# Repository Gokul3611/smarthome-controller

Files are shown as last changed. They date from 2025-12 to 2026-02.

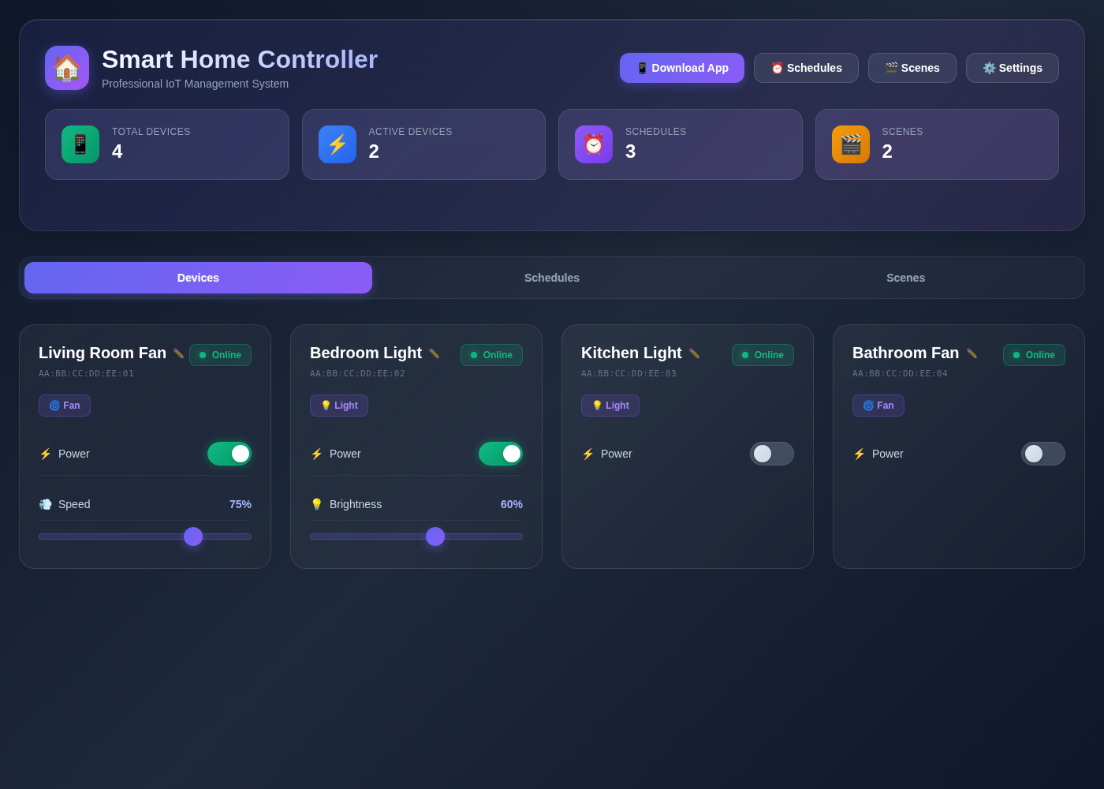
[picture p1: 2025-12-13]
docs/ui-redesign-preview.png

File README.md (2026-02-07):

"# Smart Home Controller





Full-stack IoT home automation system with ESP32 firmware, Google Apps Script backend, web dashboard, and Flutter mobile app. Controls 4 AC load channels via TRIAC phase-angle dimming with cloud synchronization, scheduling, and Amazon Alexa voice control.

## Project Status

**Maturity**: Portfolio project / advanced prototype
**Tested on**: ESP32-WROOM-32 with custom TRIAC controller board
**Known limitations**:
- Google Assistant integration (SinricPro) is stubbed but not yet functional
- No automated test suite for firmware or backend
- Flutter app requires manual API URL configuration

**What works**:
- 4-channel TRIAC phase-angle control with zero-cross detection
- Amazon Alexa voice control (via Espalexa, local network)
- Google Apps Script cloud backend with polling
- Web dashboard with real-time device control
- Flutter mobile app with device control, schedules, and scenes
- OTA firmware updates with rollback protection
- Scene and schedule automation
- WebSocket real-time state sync
- Persistent storage across reboots
- GitHub Actions CI for automated APK builds

**Not yet implemented**:
- Google Assistant control (SinricPro code is stubbed)
- Automated tests

## UI Preview

Smart Home Controller Dashboard

*Web dashboard with real-time device control and system statistics*

## Quick Start

1. **Deploy backend** — Copy `backend/google-apps-script/` files to a Google Apps Script project and deploy as a web app. See [Deployment Guide](./DEPLOYMENT.md).
2. **Flash firmware** — Open `firmware/main/main.ino` in Arduino IDE, set your Apps Script URL, and upload to ESP32. See [Installation Guide](./INSTALL.md).
3. **Build mobile app** — Run `flutter build apk --release` in `frontend/flutter project/demo/`. Or download from [Releases](https://github.com/Gokul3611/smarthome-controller/releases/latest).

## Documentation

- [Deployment Guide](./DEPLOYMENT.md) — Full system setup
- [Installation Guide](./INSTALL.md) — Firmware and hardware setup
- [Features List](./FEATURES.md) — Complete feature documentation
- [Hardware Guide](./hardware/README.md) — Circuit diagrams and assembly
- [OTA Updates](./OTA_GUIDE.md) — Firmware update procedures
- [Mobile App](./app/README.md) — APK download and build instructions
- [Backend & Dashboard](./backend/google-apps-script/README.md) — API and web dashboard
- [Bill of Materials](./hardware/bom/BOM.md) — Component list and cost
- [Security Practices](./docs/SECURITY_BEST_PRACTICES.md) — Security considerations

## System Architecture

### Components

- **Multi-core architecture**: Time-critical TRIAC control on Core 1, network operations on Core 0
- **Amazon Alexa**: Voice control via Espalexa (local network discovery)
- **Cloud backend**: Google Apps Script + Google Sheets for remote control and configuration
- **Web dashboard**: HTML5 control panel served from Apps Script
- **Flutter mobile app**: Cross-platform app with device control, schedules, and scenes
- **OTA updates**: Over-the-air firmware updates with rollback protection
- **Scenes & schedules**: Automation and preset device combinations
- **Safety features**: Watchdog timers, zero-cross monitoring, auto-shutoff
- **Persistent storage**: Configuration and state retention across reboots

## Repository Structure

```
smarthome-controller/
├── firmware/                      # ESP32 firmware code
│   ├── main/                     # Main 4-channel controller firmware
│   └── mini_controller/          # Simplified single-channel variant
├── backend/                       # Cloud backend
│   └── google-apps-script/       # Google Apps Script API + web dashboard
├── frontend/                      # Mobile app
│   └── flutter project/demo/     # Flutter cross-platform app
├── hardware/                      # Hardware design files
│   ├── pcb/                      # KiCad PCB design
│   ├── schematics/               # Circuit diagrams
│   └── bom/                      # Bill of materials
├── app/                          # Android APK builds (via CI)
├── docs/                         # Additional documentation
├── DEPLOYMENT.md                 # Full system deployment guide
├── INSTALL.md                    # Firmware installation and setup
├── FEATURES.md                   # Feature list
├── OTA_GUIDE.md                  # OTA update procedures
└── CHANGELOG.md                  # Version history
```

## Hardware Requirements

### ESP32 Module
- ESP32-WROOM-32 or compatible
- Minimum 4MB flash
- Dual-core operation

### TRIAC Controller Hardware
- 4x TRIAC channels (BT136 or similar)
- Zero-cross detection circuit
- MOC3021/3041 optocouplers
- 5V power supply

### Pin Configuration

| Function | GPIO Pin | Notes |
|---|---|---|
| Zero-Cross Detection | 13 | Rising edge interrupt |
| TRIAC 1 | 16 | Channel 1 control |
| TRIAC 2 | 17 | Channel 2 control |
| TRIAC 3 | 18 | Channel 3 control |
| TRIAC 4 | 19 | Channel 4 control |
| Switch 1 | 32 | Physical button input |
| Switch 2 | 33 | Physical button input |
| Switch 3 | 25 | Physical button input |
| Switch 4 | 26 | Physical button input |

## Software Architecture

### Core Separation

```
CORE 1 (PRO_CPU) - TIME-CRITICAL:
├── Zero-cross detection ISR (RISING edge @ GPIO13)
├── Hardware timer ISR for phase-angle control (100µs intervals)
├── TRIAC firing with <50µs accuracy
└── NO blocking calls or network operations

CORE 0 (APP_CPU) - CONNECTIVITY:
├── WiFi management with auto-reconnect
├── Google Apps Script cloud polling (2.5s interval)
├── Alexa voice assistant handling
├── Physical switch debouncing
├── Web servers (port 80, 8080, WebSocket 81)
├── OTA update handling
├── Schedule execution
├── Scene activation
├── Fade transitions
└── Watchdog monitoring (15s timeout)
```

### Data Flow

```
Physical Switch → Debounce → Device State Update → TRIAC Control
                                      ↓
                            Cloud Sync / WebSocket Broadcast

Voice Command → Alexa → Device State Update → TRIAC Control
                                      ↓
                            Cloud Sync / WebSocket Broadcast
```

## Local REST API (Port 8080)

| Endpoint | Method | Description |
|---|---|---|
| `/status` | GET | Current device states |
| `/control` | POST | Control a device (`{"id": 0, "state": true, "brightness": 75}`) |
| `/info` | GET | System information (firmware, IP, uptime, RSSI, heap) |
| `/config` | POST | Update device configuration |
| `/schedules` | GET/POST | List or create schedules |
| `/schedules/{id}` | DELETE | Delete a schedule |
| `/scenes` | GET/POST | List or create scenes |
| `/scenes/{id}/activate` | POST | Activate a scene |
| `/scenes/{id}` | DELETE | Delete a scene |
| `/restart` | POST | Restart device |
| `/factory-reset` | POST | Factory reset (requires `{"confirm": true}`) |

WebSocket on port 81 provides real-time device state updates.

## License

MIT License — See [LICENSE](./LICENSE) file for details.

## Support

- **Issues**: https://github.com/Gokul3611/smarthome-controller/issues"

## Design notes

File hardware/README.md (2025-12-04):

# Hardware Documentation

This folder contains all hardware-related documentation for the Smart Home Controller project.

## 📁 Contents

- **schematics/** - Circuit diagrams and schematics
- **pcb/** - PCB layouts and Gerber files
- **bom/** - Bill of Materials
- **README.md** - This file
- **CONNECTION_GUIDE.md** - Detailed connection instructions
- **SPECIFICATIONS.md** - Hardware specifications

---

## 🔌 Hardware Overview

The Smart Home Controller is built around the ESP32 microcontroller and controls 4 channels of AC loads using TRIAC-based dimmer circuits.

### Main Components

1. **ESP32-WROOM-32** - Main microcontroller
2. **TRIAC BT136** (x4) - AC switching elements
3. **MOC3021/3041** (x4) - Optocouplers for isolation
4. **Zero-Cross Detection Circuit** - AC waveform synchronization
5. **5V Power Supply** - Regulated power for ESP32
6. **Physical Switches** (x4) - Manual control buttons

---

## 📐 Circuit Architecture

```
AC Mains → Zero-Cross Detection → ESP32 GPIO13 (Interrupt)
                ↓
         Isolation Transformer
                ↓
         Rectifier & Regulator (5V)
                ↓
            ESP32 Power

AC Load 1-4 ← TRIAC 1-4 ← MOC3021 ← ESP32 GPIO 16-19
```

### Signal Flow

1. **Zero-Cross Detection**: Monitors AC waveform zero-crossing points
2. **ESP32 Processing**: Calculates firing angle for TRIAC
3. **Optocoupler Isolation**: Electrically isolates control from high voltage
4. **TRIAC Switching**: Controls AC power to loads

---

## 🎛️ Pin Configuration

### ESP32 GPIO Mapping

| Function | GPIO Pin | Direction | Notes |
|---|---|---|---|
| Zero-Cross Detection | GPIO 13 | Input | Rising edge interrupt, pull-down |
| TRIAC Channel 1 | GPIO 16 | Output | Active HIGH, controls optocoupler |
| TRIAC Channel 2 | GPIO 17 | Output | Active HIGH, controls optocoupler |
| TRIAC Channel 3 | GPIO 18 | Output | Active HIGH, controls optocoupler |
| TRIAC Channel 4 | GPIO 19 | Output | Active HIGH, controls optocoupler |
| Physical Switch 1 | GPIO 32 | Input | Pull-up, active LOW |
| Physical Switch 2 | GPIO 33 | Input | Pull-up, active LOW |
| Physical Switch 3 | GPIO 25 | Input | Pull-up, active LOW |
| Physical Switch 4 | GPIO 26 | Input | Pull-up, active LOW |
| Status LED | GPIO 2 | Output | Built-in LED |

### Power Pins

| Pin | Connection | Notes |
|-----|---|---|
| 3V3 | 3.3V Output | For sensors (max 500mA) |
| 5V | 5V Input | From power supply |
| GND | Ground | Common ground |

---

## ⚠️ Safety Considerations

### Electrical Safety

1. **High Voltage Warning**: This circuit operates with mains AC voltage (110V/220V)
2. **Isolation Required**: Always use optocouplers for high voltage isolation
3. **Proper Grounding**: Ensure all metal parts are properly grounded
4. **Enclosure**: Use non-conductive, fire-resistant enclosure
5. **Fusing**: Include appropriate fuses (2A-10A depending on load)

### Design Safety Features

- ✅ Optocoupler isolation (2.5kV minimum)
- ✅ Zero-cross detection for smooth switching
- ✅ Watchdog timers in firmware
- ✅ Auto-shutoff after timeout
- ✅ Brownout detection
- ✅ Overcurrent protection (via fuses)

---

## 🔧 Component Specifications

### ESP32-WROOM-32

- **CPU**: Dual-core Xtensa LX6 @ 240MHz
- **RAM**: 520KB SRAM
- **Flash**: 4MB (minimum)
- **WiFi**: 802.11 b/g/n (2.4GHz)
- **Bluetooth**: BLE 4.2
- **GPIO**: 34 programmable pins
- **ADC**: 12-bit, 18 channels
- **Operating Voltage**: 3.3V (5V tolerant on some pins)
- **Operating Current**: 80mA (average), 500mA (peak)

### TRIAC BT136

- **Type**: Bidirectional thyristor
- **Voltage Rating**: 600V or 800V
- **Current Rating**: 4A RMS
- **Gate Trigger Current**: 5-50mA
- **Package**: TO-220
- **Operating Temperature**: -40°C to +125°C

### MOC3021/3041 Optocoupler

- **Type**: TRIAC driver optocoupler
- **Isolation Voltage**: 5000V RMS
- **Forward Current**: 10-30mA
- **Zero-Cross**: 3041 has built-in zero-cross detection
- **Package**: DIP-6
- **LED Forward Voltage**: 1.5V typical

### Zero-Cross Detection Circuit

- **Input**: AC mains (via step-down transformer)
- **Output**: Digital pulse at zero-crossing
- **Frequency**: 100/120 Hz (50/60Hz mains × 2)
- **Components**: Bridge rectifier, resistor divider, optocoupler

---

## 📊 Power Requirements

### ESP32 Power Budget

| Component | Typical | Peak | Notes |
|---|---|---|---|
| ESP32 (WiFi active) | 80mA | 500mA | During transmission |
| ESP32 (WiFi idle) | 20mA | 50mA | Background processes |
| Zero-cross circuit | 5mA | 10mA | Continuous |
| Optocouplers (per channel) | 10mA | 20mA | When active |
| Status LEDs | 20mA | 20mA | Optional |
| **Total (all channels ON)** | **165mA** | **630mA** | Use 1A supply |

**Recommended**: 5V 2A power supply (with margin)

### Load Capacity

Each TRIAC channel can handle:
- **Resistive loads**: Up to 4A (880W @ 220V, 440W @ 110V)
- **Inductive loads**: Derate to 2A (440W @ 220V, 220W @ 110V)
- **LED loads**: Use compatible TRIACs or add snubber circuit

---

## 🛠️ Assembly Instructions

### PCB Assembly Order

1. **Solder SMD components first** (if any)
2. **Low-profile components** (resistors, diodes, small capacitors)
3. **Optocouplers** (DIP-6 packages)
4. **Power supply components** (transformer, rectifier, regulator)
5. **TRIACs** (TO-220 packages with heatsinks)
6. **Connectors** (screw terminals, headers)
7. **ESP32 module** (last, to avoid heat damage)

### Testing Procedure

1. **Visual Inspection**: Check for shorts, cold solder joints
2. **Continuity Test**: Verify connections with multimeter
3. **Power Supply Test**: Measure 5V and 3.3V rails (NO AC connected)
4. **ESP32 Programming**: Flash test firmware via USB
5. **Zero-Cross Test**: Monitor GPIO13 with oscilloscope
6. **Low-Voltage TRIAC Test**: Test with 12V AC before mains
7. **Final Test**: Connect mains AC (with proper safety precautions)

---

## 📋 Bill of Materials (BOM)

See **bom/BOM.csv** for complete component list with:
- Part numbers
- Quantities
- Suppliers
- Approximate costs

---

## 🔌 Connection Guide

See **CONNECTION_GUIDE.md** for detailed step-by-step connection instructions with diagrams.

---

## 📐 PCB Design Files

Located in **pcb/** folder:
- PCB layout files (KiCad/Eagle format)
- Gerber files for manufacturing
- 3D models
- Assembly drawings

---

## 🧪 Testing & Validation

### Functional Tests

- [ ] Zero-cross detection working (100/120Hz pulses)
- [ ] All 4 TRIAC channels switching correctly
- [ ] Physical switches responding
- [ ] WiFi connectivity established
- [ ] Cloud communication functional
- [ ] Voice assistant discovery working
- [ ] OTA update successful

### Safety Tests

- [ ] Isolation resistance > 10MΩ
- [ ] Ground continuity < 1Ω
- [ ] No voltage on low-voltage side
- [ ] Proper fuse operation
- [ ] Thermal testing (1 hour full load)
- [ ] EMI/RFI within limits

---

## 📞 Support

For hardware questions:
- Check **CONNECTION_GUIDE.md**
- Review **SPECIFICATIONS.md**
- See main project README
- Open GitHub issue

---

## ⚖️ Compliance

This design follows:
- IEC 60950-1 (Safety)
- EN 55022 (EMI)
- FCC Part 15 (Radio)
- RoHS Compliance

**Note**: Professional electrical certification required before commercial use.

---

## 📜 License

Hardware design licensed under CERN Open Hardware License v2.0

---

**Version**: 1.0  
**Last Updated**: December 2024  
**Status**: Production Ready

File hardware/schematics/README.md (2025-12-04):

# Circuit Schematics

This folder contains circuit diagrams and schematics for the Smart Home Controller.

## Files

- **main_schematic.txt** - ASCII art schematic (text format)
- **block_diagram.txt** - System block diagram
- **triac_driver.txt** - Detailed TRIAC driver circuit
- **zero_cross.txt** - Zero-cross detection circuit

## Tools

For creating/editing professional schematics:
- **KiCad** (Open source, recommended)
- **Eagle** (Autodesk)
- **EasyEDA** (Online, free)
- **Fritzing** (Beginner-friendly)

## Notes

The schematics provided are in text format for easy version control. For production, create professional schematics using PCB design software.

## Safety

All schematics include safety features:
- Optical isolation between AC and DC
- Proper fusing
- Zero-cross switching
- Snubber circuits
- Ground connections

---

**Status**: Reference designs provided in text format
**Recommendation**: Create professional schematics with PCB design tool before manufacturing

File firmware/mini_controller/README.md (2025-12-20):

# Mini LED Controller for ESP32

A simplified firmware for controlling the ESP32's built-in LED remotely through a web dashboard and REST API.

## Features

✅ **WiFi Connectivity** - Automatic connection with captive portal  
✅ **PWM Brightness Control** - 0-100% brightness control  
✅ **REST API** - Full REST API for LED control  
✅ **WebSocket** - Real-time updates to connected clients  
✅ **Web Dashboard** - Beautiful built-in web interface  
✅ **Cloud Integration** - Sync with Google Apps Script backend  
✅ **mDNS Support** - Access via `mini-led.local`  

## Hardware Requirements

- **ESP32 DevKit** or any compatible ESP32 board
- Built-in LED (typically connected to GPIO 2)

## Pin Configuration

| Component | GPIO Pin | Notes |
|---|---|---|
| Built-in LED | 2 | Default on most ESP32 boards |

> **Note:** Some ESP32 boards use different pins for the built-in LED. Check your board's documentation if GPIO 2 doesn't work. Common alternatives are GPIO 5, GPIO 16, or GPIO 22.

## Installation

### Using Arduino IDE

1. **Install ESP32 Board Support:**
   - Open Arduino IDE
   - Go to `File` → `Preferences`
   - Add this URL to "Additional Board Manager URLs":
     ```
     https://raw.githubusercontent.com/espressif/arduino-esp32/gh-pages/package_esp32_index.json
     ```
   - Go to `Tools` → `Board` → `Board Manager`
   - Search for "ESP32" and install "esp32 by Espressif Systems"

2. **Install Required Libraries:**
   - Go to `Sketch` → `Include Library` → `Manage Libraries`
   - Install the following libraries:
     - **WiFiManager** by tzapu (v2.0.16+)
     - **ArduinoJson** by Benoit Blanchon (v6.x)
     - **WebSockets** by Markus Sattler (v2.4.0+)

3. **Configure the Firmware:**
   - Open `firmware/mini_controller/mini_controller.ino`
   - Update the Google Apps Script URL (optional):
     ```cpp
     String GOOGLE_SCRIPT_URL = "your_google_script_url_here";
     ```
   - If your board uses a different LED pin, update:
     ```cpp
     #define LED_PIN 2  // Change to your board's LED pin
     ```

4. **Select Board and Upload:**
   - Go to `Tools` → `Board` → `ESP32 Arduino` → `ESP32 Dev Module`
   - Select the correct COM port under `Tools` → `Port`
   - Click `Upload` button

### Using PlatformIO

Create a `platformio.ini` file:

```ini
[env:esp32dev]
platform = espressif32
board = esp32dev
framework = arduino
monitor_speed = 115200

lib_deps = 
    tzapu/WiFiManager@^2.0.16
    bblanchon/ArduinoJson@^6.21.3
    links2004/WebSockets@^2.4.0

upload_speed = 921600
monitor_filters = esp32_exception_decoder
```

Then run:
```bash
pio run --target upload
pio device monitor
```

## First Time Setup

1. **Power on the ESP32**
   - The device will create a WiFi access point named `Mini_LED_Controller`

2. **Connect to the WiFi network**
   - From your phone or laptop, connect to `Mini_LED_Controller`
   - A captive portal should open automatically
   - If not, open your browser and go to `192.168.4.1`

3. **Configure WiFi**
   - Select your home WiFi network
   - Enter the password
   - Click "Save"

4. **Access the Web Interface**
   - Once connected, the serial monitor will show the device's IP address
   - Open a web browser and navigate to the IP address (e.g., `http://192.168.1.100:8080`)
   - Or use mDNS: `http://mini-led.local:8080`

## Usage

### Web Dashboard

Access the built-in web dashboard by opening your browser to:
- `http://<ESP32-IP-Address>:8080`
- Or via mDNS: `http://mini-led.local:8080`

The dashboard provides:
- **LED Status Indicator** - Visual feedback of LED state
- **Toggle Button** - Turn LED on/off
- **Brightness Slider** - Adjust brightness from 0-100%
- **System Status** - IP address, WiFi signal strength
- **Real-time Updates** - Automatic sync via WebSocket

### REST API

The mini controller provides a REST API on port 8080:

#### Get Device Status
```bash
GET http://<IP>:8080/status
```

Response:
```json
{
  "devices": [
    {
      "id": 0,
      "name": "Built-in LED",
      "type": "LED",
      "state": true,
      "brightness": 75,
      "runtime": 3600
    }
  ]
}
```

#### Control LED
```bash
POST http://<IP>:8080/control
Content-Type: application/json

{
  "state": true,
  "brightness": 75
}
```

Response:
```json
{
  "success": true,
  "state": true,
  "brightness": 75
}
```

#### Get System Information
```bash
GET http://<IP>:8080/info
```

Response:
```json
{
  "name": "Mini_LED_Controller",
  "device_type": "mini_controller",
  "firmware": "1.0",
  "mac": "AA:BB:CC:DD:EE:FF",
  "ip": "192.168.1.100",
  "uptime": 3600,
  "rssi": -45,
  "heap": 280000,
  "cloud_connected": true
}
```

#### Update Configuration
```bash
POST http://<IP>:8080/config
Content-Type: application/json

{
  "name": "Office LED"
}
```

### WebSocket API

Connect to `ws://<IP>:81` for real-time updates.

**Receive LED state updates:**
```json
{
  "type": "device_update",
  "id": 0,
  "state": true,
  "brightness": 75,
  "name": "Built-in LED"
}
```

**Send control commands:**
```json
{
  "action": "control",
  "state": true,
  "brightness": 50
}
```

**Request status:**
```json
{
  "action": "get_status"
}
```

### Cloud Integration

The mini controller can sync with the main Smart Home Controller's Google Apps Script backend.

**Configure the URL:**
```cpp
String GOOGLE_SCRIPT_URL = "https://script.google.com/macros/s/YOUR_SCRIPT_ID/exec";
```

**Cloud Features:**
- Automatic state synchronization every 5 seconds
- Remote control from the main dashboard
- Runtime statistics tracking
- Device name management

## Factory Reset

If you need to reconfigure WiFi:

1. Hold the `BOOT` button on the ESP32 for 10 seconds during startup
2. Or upload the firmware again with WiFiManager credentials cleared:
   ```cpp
   // Add at the start of setup()
   WiFiManager wm;
   wm.resetSettings();
   ```

## Troubleshooting

### LED Not Working

1. **Check the LED Pin:**
   - Different ESP32 boards use different pins
   - Try changing `LED_PIN` to 5, 16, or 22
   - Check your board's pinout diagram

2. **Test with Basic Blink:**
   ```cpp
   void setup() {
     pinMode(LED_PIN, OUTPUT);
   }
   void loop() {
     digitalWrite(LED_PIN, HIGH);
     delay(1000);
     digitalWrite(LED_PIN, LOW);
     delay(1000);
   }
   ```

### Can't Connect to WiFi

1. **Check Serial Monitor:**
   - Open Serial Monitor at 115200 baud
   - Look for error messages

2. **Ensure 2.4GHz WiFi:**
   - ESP32 only supports 2.4GHz networks
   - 5GHz networks won't work

3. **Factory Reset:**
   - Re-upload firmware with `wm.resetSettings()` added

### Web Interface Not Loading

1. **Check IP Address:**
   - Look in Serial Monitor for the assigned IP
   - Try accessing via mDNS: `http://mini-led.local:8080`

2. **Firewall Issues:**
   - Ensure your firewall allows connections on ports 8080 and 81
   - Try from a device on the same network

### WebSocket Not Connecting

1. **Check Browser Console:**
   - Open Developer Tools (F12)
   - Look for WebSocket errors

2. **Port Availability:**
   - Ensure port 81 is not blocked
   - Check if another service is using port 81

## Serial Monitor Output

Expected output on successful startup:

```
========================================
Mini LED Controller v1.0
========================================
[INFO] Device MAC: AA:BB:CC:DD:EE:FF
[INFO] WiFi connected: 192.168.1.100
[INFO] Signal strength: -45 dBm
[INFO] mDNS started: mini-led.local
[INFO] Redirect server started on port 80
[INFO] REST API server started on port 8080
[INFO] WebSocket server started on port 81
========================================
[INFO] System initialization complete
[INFO] Free heap: 280000 bytes
========================================

[INFO] Access web interface at: http://192.168.1.100:8080
```

## Integration with Main Dashboard

The mini controller uses the same API format as the main controller and can be integrated with the existing Google Apps Script dashboard.

**Backend Integration Steps:**

1. Add mini controller to your device registry
2. Use the `device_type: "mini_controller"` field to identify it
3. The LED will appear as Device 1 (`d1`) in cloud sync
4. Control it through the main dashboard alongside other devices

## Technical Specifications

| Specification | Value |
|---|---|
| Firmware Version | 1.0 |
| Platform | ESP32 |
| PWM Frequency | 5 kHz |
| PWM Resolution | 8-bit (0-255) |
| Brightness Levels | 101 (0-100%) |
| WiFi Standard | 802.11 b/g/n (2.4GHz) |
| REST API Port | 8080 |
| WebSocket Port | 81 |
| Cloud Sync Interval | 5 seconds |
| Memory Usage | ~50KB program, ~20KB RAM |

## Development

### Modify LED Pin

If your board uses a different LED pin:

```cpp
#define LED_PIN 5  // Change to your board's LED pin
```

### Adjust PWM Settings

For different LED characteristics:

```cpp
#define PWM_FREQUENCY 5000  // Adjust frequency (Hz)
#define PWM_RESOLUTION 8    // 8-bit = 0-255, 10-bit = 0-1023
```

### Change Device Name

```cpp
#define DEVICE_NAME "My_LED_Controller"
```

### Debug Mode

Enable verbose logging:

```cpp
// Add at the start of setup()
Serial.setDebugOutput(true);
```

## License

MIT License - Part of the Smart Home Controller Project

## Support

- **Main Project**: https://github.com/Gokul3611/smarthome-controller
- **Issues**: https://github.com/Gokul3611/smarthome-controller/issues
- **Documentation**: See main project README.md

## Related Documentation

- [Main Controller README](../../README.md)
- [Hardware Guide](../../hardware/README.md)
- [Backend Guide](../../backend/google-apps-script/README.md)
- [Deployment Guide](../../DEPLOYMENT.md)

---

**Built with ❤️ as part of the Smart Home Controller Project**

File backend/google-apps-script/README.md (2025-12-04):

# Smart Home Controller - Google Apps Script Backend

This directory contains the Google Apps Script backend that provides:
- RESTful API for ESP32 devices and mobile apps
- Google Sheets as a database
- Web dashboard for device control
- User authentication
- Scheduling and scenes management

## 📁 Files

- **Code.gs** - Main backend logic and API handlers
- **Database.gs** - Google Sheets database helper functions
- **Dashboard.html** - Web dashboard UI
- **appsscript.json** - Apps Script manifest

## 🚀 Deployment Steps

### 1. Create Google Sheets Database

1. Go to [Google Sheets](https://sheets.google.com)
2. Create a new spreadsheet named "Smart Home Controller DB"
3. Note the Spreadsheet ID from the URL: 
   ```
   https://docs.google.com/spreadsheets/d/[SPREADSHEET_ID]/edit
   ```

### 2. Create Apps Script Project

1. Go to [Google Apps Script](https://script.google.com)
2. Click "New Project"
3. Name it "Smart Home Controller Backend"

### 3. Add the Code Files

1. Delete the default `Code.gs` content
2. Copy the content from each `.gs` file in this directory to the script editor
3. Create new files using File → New → HTML file for `Dashboard.html`
4. Create `appsscript.json` using File → Project Settings → Show "appsscript.json"

### 4. Set Script Properties

1. Click Project Settings (gear icon)
2. Scroll to Script Properties
3. Add the following properties:
   - **SHEET_ID**: Your spreadsheet ID from step 1
   - **API_KEY**: Create a secure key (e.g., `smarthome-2024-RANDOM`)

### 5. Deploy as Web App

1. Click Deploy → New deployment
2. Select type: **Web app**
3. Configuration:
   - Description: "Smart Home Controller v1.0"
   - Execute as: **Me**
   - Who has access: **Anyone** (for public access) or **Anyone with Google account**
4. Click Deploy
5. Authorize the app (review permissions)
6. Copy the **Web app URL** - this is your API endpoint!

### 6. Set Up Custom Domain (Optional)

To get a memorable URL like `home.yourname.com`:

1. Go to your domain registrar (e.g., GoDaddy, Namecheap)
2. Add a CNAME record:
   ```
   Type: CNAME
   Name: home (or smarthome)
   Value: script.google.com
   ```
3. In Apps Script deployment, note your deployment ID
4. Access via: `https://script.google.com/macros/s/[DEPLOYMENT_ID]/exec`

**Note**: Apps Script URLs cannot be fully customized, but you can use URL shorteners or domain forwards.

## 📊 Database Schema

The backend automatically creates these sheets in your Google Sheets:

### Devices Sheet
| Column | Description |
|---|---|
| UID | Unique device identifier (MAC address) |
| Name | Device display name |
| Type | Device type (light/fan) |
| IP | Current IP address |
| Version | Firmware version |
| Uptime | Device uptime in seconds |
| RSSI | WiFi signal strength |
| Heap | Free heap memory |
| Last Seen | Last communication timestamp |
| User ID | Owner user ID |
| Created | Registration timestamp |

### DeviceStates Sheet
| Column | Description |
|---|---|
| UID | Device UID |
| Channel | Channel number (0-3) |
| State | Power state (true/false) |
| Value | Brightness/speed value (0-100) |
| Type | Device type |
| Timestamp | Last update time |

### Schedules Sheet
| Column | Description |
|---|---|
| ID | Schedule UUID |
| User ID | Owner user ID |
| Device UID | Target device |
| Channel | Target channel |
| Name | Schedule name |
| Start Time | Start time (HH:MM) |
| End Time | End time (HH:MM) |
| Days | Days of week (bitmask) |
| Action | Action to perform |
| Value | Value for action |
| Enabled | Schedule enabled status |
| Created | Creation timestamp |

### Scenes Sheet
| Column | Description |
|---|---|
| ID | Scene UUID |
| User ID | Owner user ID |
| Name | Scene name |
| Devices | JSON array of device states |
| Created | Creation timestamp |

### Users Sheet
| Column | Description |
|---|---|
| ID | User UUID |
| Name | User name |
| Email | User email |
| Password | Hashed password |
| Created | Registration timestamp |

### Commands Sheet
| Column | Description |
|---|---|
| UID | Target device UID |
| Command | JSON command object |
| Timestamp | Queue timestamp |
| Executed | Execution status |

## 🔌 API Endpoints

All endpoints use the web app URL as base: `https://script.google.com/macros/s/[YOUR_DEPLOYMENT_ID]/exec`

### Device Endpoints

#### Poll for Commands
```
GET/POST ?action=poll&uid=AA:BB:CC:DD:EE:FF&api_key=YOUR_KEY
```

Response:
```json
{
  "success": true,
  "config": {
    "name": "Living Room",
    "type": "fan"
  },
  "commands": [],
  "ota_update": false
}
```

#### Update Device State
```
POST ?action=update_state
Body: {
  "api_key": "YOUR_KEY",
  "uid": "AA:BB:CC:DD:EE:FF",
  "states": [
    {"channel": 0, "state": true, "value": 75}
  ]
}
```

### User Endpoints

#### Login
```
POST ?action=login
Body: {
  "api_key": "YOUR_KEY",
  "email": "user@example.com",
  "password": "password123"
}
```

#### Signup
```
POST ?action=signup
Body: {
  "api_key": "YOUR_KEY",
  "name": "John Doe",
  "email": "user@example.com",
  "password": "password123"
}
```

### Device Management

#### Get Devices
```
GET/POST ?action=get_devices&api_key=YOUR_KEY&user_id=USER_ID
```

#### Update Device
```
POST ?action=update_device
Body: {
  "api_key": "YOUR_KEY",
  "uid": "AA:BB:CC:DD:EE:FF",
  "name": "Bedroom Fan",
  "type": "fan"
}
```

#### Reset WiFi
```
POST ?action=reset_wifi
Body: {
  "api_key": "YOUR_KEY",
  "uid": "AA:BB:CC:DD:EE:FF"
}
```

### Schedule Management

#### Get Schedules
```
GET/POST ?action=get_schedules&api_key=YOUR_KEY&user_id=USER_ID
```

#### Save Schedule
```
POST ?action=save_schedule
Body: {
  "api_key": "YOUR_KEY",
  "schedule": {
    "user_id": "USER_ID",
    "device_uid": "AA:BB:CC:DD:EE:FF",
    "channel": 0,
    "name": "Morning Light",
    "start_time": "06:00",
    "end_time": "08:00",
    "days": "1111100",
    "action": "on",
    "value": 100,
    "enabled": true
  }
}
```

#### Delete Schedule
```
POST ?action=delete_schedule
Body: {
  "api_key": "YOUR_KEY",
  "schedule_id": "SCHEDULE_UUID"
}
```

### Scene Management

Similar endpoints for scenes (get_scenes, save_scene, delete_scene)

## 🌐 Web Dashboard

Access the web dashboard at:
```
https://script.google.com/macros/s/[YOUR_DEPLOYMENT_ID]/exec?page=dashboard
```

### Dashboard Features

- **Real-time Device Control**: Toggle devices on/off, adjust speed/brightness
- **Device Management**: Rename devices, change device types
- **Scheduling**: Create time-based automations
- **Scenes**: Save and activate device combinations
- **WiFi Reset**: Reset device WiFi credentials remotely
- **Download App**: Direct link to download the mobile app
- **Responsive Design**: Works on desktop, tablet, and mobile

## 🔒 Security Considerations

1. **API Key**: Change the default API key in Script Properties
2. **HTTPS**: Apps Script uses HTTPS by default
3. **Password Hashing**: Passwords are hashed using SHA-256
4. **Rate Limiting**: Consider implementing rate limiting for production
5. **CORS**: Apps Script allows cross-origin requests
6. **Authentication**: Implement token-based auth for production

## 🔧 ESP32 Integration

Configure your ESP32 to use this backend:

```cpp
// In your ESP32 code
String GOOGLE_SCRIPT_URL = "https://script.google.com/macros/s/YOUR_DEPLOYMENT_ID/exec";
String API_KEY = "smarthome-2024-YOUR_KEY";

void pollServer() {
  String url = GOOGLE_SCRIPT_URL + "?action=poll&uid=" + WiFi.macAddress() + "&api_key=" + API_KEY;
  HTTPClient http;
  http.begin(url);
  int httpCode = http.GET();
  
  if (httpCode == 200) {
    String payload = http.getString();
    // Parse JSON and execute commands
  }
  
  http.end();
}
```

## 📱 Flutter App Integration

Configure the Flutter app to use this backend:

```dart
// In lib/config/api_config.dart
class ApiConfig {
  static const String baseUrl = 'https://script.google.com/macros/s/YOUR_DEPLOYMENT_ID/exec';
  static const String apiKey = 'smarthome-2024-YOUR_KEY';
}
```

## 🐛 Troubleshooting

### Issue: "Script function not found"
- Make sure all `.gs` files are added to the project
- Verify function names match exactly

### Issue: "Unauthorized"
- Check API key is set correctly in Script Properties
- Verify API key is passed in requests

### Issue: "Spreadsheet not found"
- Verify SHEET_ID in Script Properties
- Make sure the script has access to the spreadsheet

### Issue: "Rate limit exceeded"
- Apps Script has quotas (URL Fetch calls: 20,000/day)
- Implement caching and reduce polling frequency

## 📈 Performance Tips

1. **Caching**: Use Apps Script CacheService for frequently accessed data
2. **Batch Operations**: Group database operations to reduce execution time
3. **Async Processing**: Use time-driven triggers for background tasks
4. **Optimize Queries**: Minimize sheet reads/writes
5. **CDN**: Host static assets (images, CSS) on a CDN

## 📝 License

MIT License - Same as the main project

## 🆘 Support

For issues or questions:
- GitHub Issues: [smarthome-controller/issues](https://github.com/Gokul3611/smarthome-controller/issues)
- Documentation: Check the main README.md

---

**Deployment Checklist:**
- [ ] Create Google Sheets database
- [ ] Create Apps Script project
- [ ] Copy all code files
- [ ] Set Script Properties (SHEET_ID, API_KEY)
- [ ] Deploy as web app
- [ ] Test API endpoints
- [ ] Configure ESP32 with deployment URL
- [ ] Configure Flutter app with deployment URL
- [ ] Test dashboard access
- [ ] Set up custom domain (optional)

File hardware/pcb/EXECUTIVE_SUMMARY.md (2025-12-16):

# Smart Home Controller - PCB Manufacturing Executive Summary

## Project Overview

**Project Name**: Smart Home Controller  
**Version**: 1.0  
**PCB Revision**: Rev A  
**Design Tool**: KiCad 6.0  
**Manufacturer**: JLCPCB  
**Date**: December 2024

---

## Circuit Specifications

### Main Controller
- **Microcontroller**: ESP32-WROOM-32
- **Operating Voltage**: 3.3V logic, 5V power input
- **WiFi**: 802.11 b/g/n (2.4GHz)
- **Bluetooth**: BLE 4.2

### GPIO Pin Assignments

| Function | GPIO Pin | Direction | Notes |
|---|---|---|---|
| Zero-Cross Detection | GPIO 13 | Input | Rising edge interrupt, pull-down 10kΩ |
| TRIAC Channel 1 | GPIO 16 | Output | Active HIGH, drives MOC3021 via 330Ω |
| TRIAC Channel 2 | GPIO 17 | Output | Active HIGH, drives MOC3021 via 330Ω |
| TRIAC Channel 3 | GPIO 18 | Output | Active HIGH, drives MOC3021 via 330Ω |
| TRIAC Channel 4 | GPIO 19 | Output | Active HIGH, drives MOC3021 via 330Ω |
| Physical Switch 1 | GPIO 32 | Input | Pull-up, active LOW, debounced |
| Physical Switch 2 | GPIO 33 | Input | Pull-up, active LOW, debounced |
| Physical Switch 3 | GPIO 25 | Input | Pull-up, active LOW, debounced |
| Physical Switch 4 | GPIO 26 | Input | Pull-up, active LOW, debounced |
| Status LED | GPIO 2 | Output | Built-in LED |

### TRIAC Driver Circuits (4 Channels)

Each channel consists of:
1. **Optocoupler**: MOC3021 (random phase) or MOC3041 (zero-cross)
   - Input: 330Ω current limiting resistor from ESP32 GPIO
   - Isolation: 5000V RMS
   
2. **TRIAC**: BT136-600E
   - Voltage Rating: 600V
   - Current Rating: 4A RMS
   - Package: TO-220 with heatsink
   - Gate Resistor: 100Ω (1/2W)
   - Snubber Circuit: 0.1µF/400V film capacitor + 100kΩ resistor (optional)

3. **Thermal Management**:
   - Heatsinks on all TRIACs (TO-220 compatible)
   - Thermal vias under TRIAC mounting pads (0.5mm diameter, filled)
   - Minimum 9 thermal vias per TRIAC in 3x3 grid pattern
   - Thermal pad connection to bottom copper pour

### Zero-Cross Detection Circuit

- **Input**: AC mains via step-down transformer (230V to 12V)
- **Rectifier**: Bridge rectifier using 4x 1N4007 diodes
- **Optocoupler**: 4N25 or PC817
- **Current Limiting**: 1kΩ resistor (1/2W) on AC side
- **Pull-down**: 10kΩ resistor on ESP32 side
- **Output**: Digital pulse at each zero-crossing (100Hz for 50Hz mains, 120Hz for 60Hz mains)
- **Protection**: 0.1µF ceramic capacitor for noise filtering

### Power Supply Circuit

- **Input**: AC mains via isolation transformer (230V/110V to 12V AC, 2VA minimum)
- **Rectifier**: Full-wave bridge rectifier (1N4007 x4)
- **Filter**: 1000µF/16V electrolytic capacitor
- **Regulator**: AMS1117-5.0 (5V, 1A)
- **Output Filter**: 100µF/16V + 10µF/16V electrolytic capacitors
- **Bypass**: 0.1µF ceramic capacitors at ESP32 power pins
- **Protection**: Reverse polarity protection diode, input fuse (2A)

---

## PCB Design Requirements

### Board Specifications

- **Dimensions**: 100mm x 80mm
- **Layers**: 2-layer PCB
- **Copper Weight**: 2oz (70µm) on both layers for high current handling
- **Board Thickness**: 1.6mm (standard)
- **Surface Finish**: HASL (Hot Air Solder Leveling) or ENIG
- **Solder Mask**: Green (standard) or other color
- **Silkscreen**: White text on both sides

### Critical Design Rules

#### AC/DC Isolation Barrier
- **Location**: Y = 26mm from bottom edge
- **Barrier Width**: 6mm minimum clearance zone
- **No Traces**: Absolutely no copper traces crossing the barrier
- **No Vias**: No vias within the isolation barrier zone
- **Keepout**: Defined keepout area in PCB layout
- **Creepage**: Minimum 6mm creepage distance between AC and DC sides
- **Clearance**: Minimum 6mm clearance in air

#### Copper Clearances
- **High Voltage AC traces**: 0.8mm minimum spacing
- **Low Voltage DC traces**: 0.2mm minimum spacing
- **AC to DC clearance**: 6mm minimum (enforced by isolation barrier)
- **Trace Width (AC)**: 1.5mm minimum for 4A loads
- **Trace Width (DC, 5V)**: 0.8mm for power, 0.3mm for signals

#### Thermal Management
- **TRIAC Thermal Vias**: 
  - 9 vias per TRIAC in 3x3 grid pattern
  - Via diameter: 0.5mm drill, 0.8mm pad
  - Via spacing: 2mm center-to-center
  - Connected to bottom layer ground/heat sink plane
  - Filled or tented vias recommended

- **Copper Pours**:
  - Bottom layer: Ground plane with thermal relief for TRIACs
  - Top layer: Ground pour in non-AC areas
  - Thermal connection from TRIAC tab to ground plane

### Component Placement

#### High Voltage Side (Below Y=26mm barrier)
- AC input screw terminals
- Transformer
- Bridge rectifier
- TRIACs (BT136) with heatsinks
- MOC3021 optocouplers (straddling barrier)
- AC load output screw terminals
- Fuses and protection components

#### Low Voltage Side (Above Y=26mm barrier)
- ESP32-WROOM-32 module
- 5V voltage regulator (AMS1117)
- Zero-cross detection optocoupler output
- Physical switches
- Status LEDs
- Bypass capacitors
- Programming header (USB/UART)

#### Optocoupler Placement
- MOC3021 optocouplers should straddle the isolation barrier
- Input pins (1-2) on low voltage side
- Output pins (4-6) on high voltage side
- Package oriented perpendicular to barrier

### Net Connections

#### Power Nets
- **AC_LIVE**: Mains live input
- **AC_NEUTRAL**: Mains neutral input
- **AC_L1, AC_L2, AC_L3, AC_L4**: TRIAC switched outputs to loads
- **+5V**: Regulated 5V power rail
- **+3V3**: 3.3V from ESP32 regulator
- **GND**: Common ground (DC side only, isolated from AC)

#### Signal Nets
- **ZCD**: Zero-cross detection signal to GPIO13
- **TRIAC1**: GPIO16 to MOC3021 channel 1
- **TRIAC2**: GPIO17 to MOC3021 channel 2
- **TRIAC3**: GPIO18 to MOC3021 channel 3
- **TRIAC4**: GPIO19 to MOC3021 channel 4
- **SW1**: Physical switch 1 to GPIO32
- **SW2**: Physical switch 2 to GPIO33
- **SW3**: Physical switch 3 to GPIO25
- **SW4**: Physical switch 4 to GPIO26

---

## Manufacturing Specifications (JLCPCB)

### PCB Fabrication Parameters

```
Board Type: Single PCB
Layers: 2
Dimensions: 100mm x 80mm
PCB Qty: 5 (minimum order)
PCB Thickness: 1.6mm
PCB Color: Green
Silkscreen: White
Surface Finish: HASL (Lead Free)
Outer Copper Weight: 2oz
Via Covering: Tented
Via Process: Tented vias (recommended for thermal vias)
Plating Thickness: 1oz (25µm) minimum on via walls
Gold Fingers: No
Castellated Holes: No
Material: FR-4 TG150
Dielectric Constant: 4.5 @ 1MHz
Remove Order Number: Yes (specify location on back silkscreen)
Controlled Impedance: No (not required for this design)
```

### Stackup Configuration

```
Layer 1 (Top):    0.07mm copper (2oz) - F.Cu - Signal/Power layer
Dielectric:       1.46mm FR-4 core (εr = 4.5)
Layer 2 (Bottom): 0.07mm copper (2oz) - B.Cu - Ground plane
```

### Via Specifications for Thermal Management

- **Thermal Via Fill**: Tented (covered with solder mask)
- **Via Plating**: Standard through-hole plating (1oz min)
- **Thermal Via Pattern**: 3×3 grid under each TRIAC
- **Via Spacing**: 2mm center-to-center
- **Via Function**: Heat transfer from TRIAC to bottom ground plane

### Gerber Files Required

1. **GTL** - Top copper layer
2. **GBL** - Bottom copper layer
3. **GTS** - Top solder mask
4. **GBS** - Bottom solder mask
5. **GTO** - Top silkscreen
6. **GBO** - Bottom silkscreen
7. **TXT** - Drill file (Excellon format)
8. **GML/GKO** - Board outline

### Design Rule Constraints (JLCPCB Standard)

- **Minimum Track Width**: 0.127mm (use 0.3mm minimum for this design)
- **Minimum Track Spacing**: 0.127mm (use 0.8mm for AC, 0.2mm for DC)
- **Minimum Via Hole Size**: 0.3mm (use 0.5mm)
- **Minimum Via Diameter**: 0.5mm (use 0.8mm)
- **PTH Drill Sizes**: 0.3mm - 6.3mm
- **NPTH Drill Sizes**: 0.5mm - 6.3mm
- **Board Outline Tolerance**: ±0.2mm

### Assembly (If Using JLCPCB Assembly Service)

- Basic assembly available for common SMD components
- Through-hole components (TRIACs, transformers) require manual assembly
- Extended parts library available at additional cost
- BOM and Pick-and-Place (CPL) files required

---

## Safety & Compliance

### Electrical Safety

1. **Isolation Requirements**:
   - Minimum 6mm AC/DC isolation barrier enforced
   - Optocoupler isolation rating: 5000V RMS minimum
   - No direct electrical connection between AC and DC sides

2. **Protection Features**:
   - Input fuse on AC side (2A slow-blow)
   - Reverse polarity protection on DC input
   - ESD protection on exposed connectors
   - Thermal shutdown in firmware

3. **Grounding**:
   - AC ground terminal provided
   - Metal enclosure must be grounded
   - DC ground isolated from AC ground

### Regulatory Compliance

- **Target Standards**:
  - IEC 60950-1: Safety of IT equipment
  - EN 55022: EMI emissions
  - FCC Part 15: Radio frequency devices
  - RoHS: Restriction of hazardous substances

- **Testing Required**:
  - Hipot testing (isolation voltage)
  - Ground bond testing
  - EMI/RFI emissions testing
  - Safety agency approval (UL/CE) for commercial use

### Warnings

⚠️ **HIGH VOLTAGE WARNING**: This device operates with mains AC voltage (110-240V) which can cause serious injury or death. Assembly and installation should only be performed by qualified personnel familiar with high voltage safety procedures.

⚠️ **ISOLATION CRITICAL**: The 6mm isolation barrier is a critical safety feature. Do not modify or bypass this barrier. Any design changes must maintain minimum isolation requirements.

---

## Testing & Quality Control

### Pre-Power Testing
1. Visual inspection of PCB assembly
2. Continuity testing of all connections
3. Isolation resistance testing (AC to DC >10MΩ)
4. Short circuit check on power rails
5. Verify correct component orientation (especially diodes, ICs)

### Low-Voltage Testing
1. Apply 5V power (no AC connected)
2. Verify 3.3V regulator output
3. Program ESP32 with test firmware
4. Test GPIO inputs/outputs
5. Verify WiFi connectivity

### High-Voltage Testing (With Safety Precautions)
1. Connect low-voltage AC (12V) to test TRIACs
2. Verify zero-cross detection timing
3. Test TRIAC switching at various duty cycles
4. Monitor TRIAC temperatures under load
5. Test with full mains voltage (final step)

### Production Testing
- [ ] PCB visual inspection (IPC-A-610 standards)
- [ ] Automated optical inspection (AOI)
- [ ] In-circuit testing (ICT) if available
- [ ] Functional testing with test fixture
- [ ] Burn-in testing (24 hours at full load)
- [ ] Final QC inspection and packaging

---

## Bill of Materials Reference

See `BOM.csv` for complete component list including:
- Part numbers
- Manufacturer part numbers (MPN)
- Quantities
- Reference designators
- Footprints
- Supplier information
- Pricing

---

## Revision History

| Version | Date | Changes | Author |
|---|---|---|---|
| 1.0 | Dec 2024 | Initial release for production | Engineering Team |

---

## Contact & Support

**Project Repository**: [GitHub Repository URL]  
**Technical Support**: Open GitHub issue with "Hardware:" prefix  
**Safety Questions**: Consult licensed electrician  

---

**Document Status**: Production Ready  
**Approved By**: Engineering Team  
**Approval Date**: December 2024

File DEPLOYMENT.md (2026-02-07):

# Deployment Guide

This guide walks you through deploying the entire Smart Home Controller system.

## Prerequisites

- Google Account (for Apps Script and Sheets)
- Flutter SDK installed (for mobile app)
- Arduino IDE or PlatformIO (for ESP32)
- ESP32 development board
- Basic knowledge of JavaScript, Dart, and C++

---

## Step 1: Backend Setup

1. **Create Google Sheets Database**
   1. Go to https://sheets.google.com
   2. Create new spreadsheet: "Smart Home Controller DB"
   3. Copy Spreadsheet ID from URL

2. **Deploy Apps Script Backend**
   1. Go to https://script.google.com
   2. New Project → "Smart Home Controller"
   3. Copy all files from `backend/google-apps-script/`
   4. Set Script Properties:
      - `SHEET_ID`: your spreadsheet ID
      - `API_KEY`: `smarthome-2024-<random string>`
   5. Deploy → New deployment → Web app
   6. Execute as: Me; Who has access: Anyone
   7. Copy Web App URL

The web dashboard is automatically deployed with the backend. Access it at: `[Your Web App URL]?page=dashboard`

The backend will auto-create the required sheets (Devices, DeviceStates, Schedules, Scenes, Users, Commands) on first use.

---

## Step 2: Configure and Build Flutter App

1. **Update API Configuration**
   ```dart
   // Edit: frontend/flutter project/demo/lib/config/api_config.dart
   static const String baseUrl = 'YOUR_WEB_APP_URL';
   static const String apiKey = 'YOUR_API_KEY';
   ```

2. **Build APK**
   ```bash
   cd "frontend/flutter project/demo"
   flutter pub get
   flutter build apk --release
   ```

3. The APK is at `build/app/outputs/flutter-apk/app-release.apk`. Install it on your Android device.

---

## Step 3: Configure and Flash ESP32

1. **Update Firmware Configuration**
   ```cpp
   // Edit: firmware/main/main.ino
   String GOOGLE_SCRIPT_URL = "YOUR_WEB_APP_URL";
   String API_KEY = "YOUR_API_KEY";
   ```

2. **Flash Firmware**
   1. Open `firmware/main/main.ino` in Arduino IDE
   2. Select Board: ESP32 Dev Module
   3. Connect ESP32 via USB
   4. Click Upload

See [INSTALL.md](./INSTALL.md) for detailed Arduino IDE/PlatformIO setup and library installation.

---

## Step 4: First Run

1. Power on ESP32
2. Connect to WiFi network: `Smart_Home_Hub`
3. Open browser to `192.168.4.1`
4. Configure your WiFi network
5. Device restarts and connects
6. Open dashboard — device should appear automatically
7. Install and open the mobile app, sign up, and test control

---

## Verification Checklist

**Backend:**
- [ ] Google Sheets database created
- [ ] Apps Script deployed
- [ ] Test API: `[URL]?action=get_devices&api_key=[KEY]`
- [ ] Dashboard loads and displays correctly

**Mobile App:**
- [ ] APK builds successfully
- [ ] App installs and runs
- [ ] Can sign up / log in
- [ ] Devices appear in app

**ESP32:**
- [ ] Firmware uploads successfully
- [ ] Serial monitor (115200 baud) shows WiFi connection
- [ ] Device appears in backend and dashboard
- [ ] Control works from dashboard and app

---

## Troubleshooting

**"Apps Script execution failed"**
- Check Script Properties are set correctly
- Verify SHEET_ID matches your spreadsheet
- Re-deploy with a new version

**"No devices showing"**
- Check API URL in app config
- Verify API key matches between firmware, app, and backend
- Check ESP32 serial output for connection errors

**"ESP32 won't connect to WiFi"**
- Ensure 2.4GHz network (5GHz not supported)
- Try factory reset (hold Switch 1 for 10 seconds)
- Check serial monitor for error messages

**"Flutter build fails"**
- Run `flutter clean && flutter pub get`
- Check Flutter SDK version with `flutter doctor`

---

**Estimated deployment time**: 30–60 minutes depending on familiarity with the tools.
**Cost**: Free (using Google free tier).

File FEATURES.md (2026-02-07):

# Smart Home Controller - Features

This document lists the features implemented in the Smart Home Controller system.

## Mobile App (Flutter)

### Authentication & User Management
- User registration and login with email/password
- Password hashing
- Session management with tokens
- Profile management
- Forgot password flow

### Device Control
- Real-time device listing
- Device power toggle (on/off)
- Fan speed control (0-100%)
- Light brightness control (0-100%)
- Device renaming
- Device type selection (Light/Fan)
- Dynamic UI (fan controls appear only for fans)
- Device status indicators (online/offline)
- Multiple device support (up to 4 channels per ESP32)

### Network & Connection
- WiFi configuration interface
- WiFi password reset (from app)
- Device discovery on local network
- Connection status monitoring
- Signal strength (RSSI) display
- IP address display

### Automation
- Schedule creation (alarm-style interface)
- Time-based automation
- Day-of-week selection
- Multiple schedules per device
- Enable/disable schedules
- Schedule editing and deletion

### Scenes
- Scene creation (device combinations)
- Multi-device scene support
- Quick scene activation
- Scene naming and management
- Scene editing and deletion

### System Information
- Device statistics (uptime, memory, version)
- System information page
- FAQ section

### UI/UX
- Dark theme with glassmorphism effects
- Smooth animations
- Responsive layout
- Material Design 3

---

## Web Dashboard

### Device Management
- Real-time device grid view
- Device power control
- Fan speed sliders
- Device renaming (click on device name)
- Device type selection
- Online/offline status indicators
- Auto-refresh every 3 seconds

### Scheduling
- Visual schedule list
- Add/edit/delete schedules
- Time picker interface
- Day selection (checkboxes)
- Device selection dropdown
- Schedule enable/disable

### Scenes
- Scene management interface
- Create custom scenes
- Quick activation
- Scene editing

### Deployment
- Hosted on Google Apps Script
- HTTPS by default
- No server maintenance required

---

## Backend (Google Apps Script)

### API Endpoints
- Device polling (ESP32 checks for commands)
- Device registration
- State updates (from devices)
- Device list retrieval
- Device configuration updates
- Schedule management (CRUD)
- Scene management (CRUD)
- User authentication
- WiFi reset commands

### Database (Google Sheets)
- Devices sheet (device registry)
- DeviceStates sheet (real-time states)
- Schedules sheet (automation schedules)
- Scenes sheet (scene configurations)
- Users sheet (user accounts)
- Commands sheet (pending command queue)

### Features
- RESTful API design
- JSON request/response format
- API key authentication
- Auto-initialization of database
- Command queuing system
- 2.5s polling interval
- Device online/offline detection

---

## ESP32 Firmware

### Hardware Control
- 4-channel TRIAC phase-angle control
- Zero-cross detection
- Microsecond timing precision
- Multi-core architecture (FreeRTOS)
- Physical button inputs (4 switches)

### Network Features
- WiFi connectivity with auto-reconnect
- Captive portal for initial setup
- REST API server (ports 80, 8080)
- WebSocket server (port 81)
- Google Apps Script cloud polling

### Voice Assistants
- Amazon Alexa integration (via Espalexa, local network)
- Google Assistant via SinricPro — **stubbed, not yet functional**

### Advanced Features
- OTA firmware updates with rollback protection
- Scene execution
- Schedule execution
- Smooth fade transitions
- Watchdog timers
- Safety features (auto-shutoff, zero-cross monitoring)
- Persistent storage (Preferences)

### Local API Endpoints
- GET /status — Device states
- POST /control — Device control
- GET /info — System information
- GET/POST /schedules — Schedule management
- GET/POST /scenes — Scene management
- WebSocket — Real-time updates

---

## Security

### Authentication
- Password hashing (SHA-256)
- Token-based authentication
- API key validation
- HTTPS by default (Apps Script)

### Best Practices
- Credentials stored in Google Apps Script Properties (not in code)
- Input validation on API endpoints
- Error handling on network calls

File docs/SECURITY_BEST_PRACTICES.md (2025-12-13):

# Security Best Practices

## Overview

This document outlines security best practices implemented in the Smart Home Controller system and guidelines for maintaining security in production deployments.

---

## Web Dashboard Security

### XSS Protection

**Implemented:**
- All user-provided data (device names, UIDs, scene names, schedule names) is sanitized using HTML escaping
- Input validation on all forms with length limits
- Content Security Policy (CSP) headers should be configured on the web server

**Code Example:**
```javascript
// HTML escape function prevents XSS attacks
function escapeHtml(text) {
  const map = {
    '&': '&amp;',
    '<': '&lt;',
    '>': '&gt;',
    '"': '&quot;',
    "'": '&#039;'
  };
  return String(text).replace(/[&<>"']/g, m => map[m]);
}

// Usage in rendering
const safeName = escapeHtml(device.name);
```

### Input Validation

**Implemented:**
- Device names: max 30 characters
- Schedule names: max 50 characters
- Scene names: max 50 characters
- Scene descriptions: max 200 characters
- All inputs are trimmed before processing

### API Security

**Implemented:**
- API key authentication (`smarthome-2024`)
- HTTPS recommended for all communications
- Network error handling with user feedback

**Recommendations:**
1. Change the default API key in production
2. Implement rate limiting on the backend
3. Use environment variables for API keys
4. Enable CORS with specific origin restrictions
5. Implement session management for user authentication

---

## Firmware Security

### Network Security

**Implemented:**
- WiFiManager for secure WiFi credential storage
- HTTPS support for cloud communications
- MAC address-based device identification

**Recommendations:**
1. Enable WPA3 encryption on your WiFi network
2. Use a separate IoT VLAN for smart home devices
3. Implement device-specific API keys (instead of shared key)
4. Regular firmware updates via OTA

### Over-The-Air (OTA) Updates

**Implemented:**
- Rollback protection
- Signature verification (recommended to enable)
- HTTPS for firmware downloads

**Best Practices:**
1. Test firmware updates in a staging environment first
2. Use signed firmware images
3. Implement version checking before updates
4. Monitor update success rates

### Physical Security

**Recommendations:**
1. Disable debug ports in production builds
2. Secure physical access to ESP32 devices
3. Consider tamper detection mechanisms
4. Implement secure boot (ESP32 feature)

---

## Mobile App Security

### Data Protection

**Implemented:**
- Secure HTTPS communications
- Input validation on all forms
- Error handling that doesn't expose sensitive data

**Recommendations:**
1. Implement certificate pinning for API communications
2. Store sensitive data in secure storage (Android Keystore, iOS Keychain)
3. Implement biometric authentication
4. Add app-level encryption for cached data
5. Clear sensitive data on logout

### API Communications

**Best Practices:**
1. Never hardcode API keys in the app
2. Use secure token-based authentication
3. Implement request signing
4. Add request/response encryption
5. Handle network timeouts gracefully

---

## Backend Security (Google Apps Script)

### Access Control

**Implemented:**
- API key authentication
- Action-based routing

**Recommendations:**
1. Implement user-based authentication with JWT tokens
2. Add role-based access control (RBAC)
3. Log all API access for audit trails
4. Implement IP whitelisting if possible
5. Rate limiting per user/device

### Data Storage

**Best Practices:**
1. Don't store passwords in plain text
2. Use hashed passwords with salt (bcrypt, scrypt)
3. Encrypt sensitive device data
4. Regular database backups
5. Implement data retention policies

### Script Security

**Recommendations:**
1. Validate all input parameters
2. Use prepared statements or sanitization for database queries
3. Limit script permissions to minimum required
4. Regular security audits
5. Keep dependencies updated

---

## Network Security

### Device Communication

**Recommendations:**
1. Use a dedicated IoT network/VLAN
2. Implement network segmentation
3. Configure firewall rules:
   - Block incoming connections to ESP32 devices from internet
   - Allow only necessary outbound connections
   - Restrict local network access
4. Disable UPnP on routers
5. Regular network security audits

### Port Security

**Open Ports (ESP32):**
- Port 80: HTTP redirect server
- Port 8080: Local REST API
- Port 81: WebSocket server

**Best Practices:**
1. Close unnecessary ports
2. Use firewall rules to restrict access
3. Consider VPN for remote access instead of port forwarding
4. Monitor for suspicious connection attempts

---

## Monitoring & Incident Response

### Logging

**Implemented:**
- Console logging for debugging
- Error tracking in web dashboard

**Recommendations:**
1. Implement centralized logging
2. Log security-relevant events:
   - Failed authentication attempts
   - Unusual API usage patterns
   - Device connection/disconnection
   - Configuration changes
3. Set up alerts for suspicious activities
4. Regular log reviews

### Incident Response

**Preparation:**
1. Document incident response procedures
2. Maintain contact list for security issues
3. Regular security training
4. Test incident response plan

**Response Steps:**
1. Identify and contain the threat
2. Assess the impact
3. Remediate vulnerabilities
4. Document lessons learned
5. Update security measures

---

## Compliance & Privacy

### Data Privacy

**Considerations:**
1. Inform users about data collection
2. Implement data minimization
3. Provide data export/deletion capabilities
4. Comply with GDPR, CCPA, or relevant regulations
5. Regular privacy audits

### Documentation

**Maintain:**
1. Privacy policy
2. Terms of service
3. Security incident log
4. Change management records
5. Audit trails

---

## Regular Maintenance

### Security Updates

**Schedule:**
- Weekly: Review security advisories for dependencies
- Monthly: Update dependencies and libraries
- Quarterly: Security audit and penetration testing
- Annually: Comprehensive security review

### Checklist

- [ ] Update all dependencies to latest secure versions
- [ ] Review and rotate API keys
- [ ] Audit user access and permissions
- [ ] Review firewall and network rules
- [ ] Test backup and recovery procedures
- [ ] Update documentation
- [ ] Train team on security best practices
- [ ] Review incident response plan

---

## Security Resources

### Tools

- **OWASP ZAP**: Web application security scanner
- **Wireshark**: Network traffic analysis
- **ESP32 Secure Boot**: Firmware integrity verification
- **SSL Labs**: SSL/TLS configuration checker

### References

- OWASP IoT Security Top 10
- NIST Cybersecurity Framework
- IoT Security Foundation Best Practices
- ESP32 Security Features Guide

---

## Contact

For security issues or questions:
- **Security Email**: security@smarthome-controller.com
- **Issue Tracker**: https://github.com/Gokul3611/smarthome-controller/security

**Please report security vulnerabilities privately before public disclosure.**

---

*Last Updated: December 2024*
*Version: 1.0*

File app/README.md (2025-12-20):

# Smart Home Controller - Android APK

This folder contains the Android APK builds for the Smart Home Controller mobile application.

## 📱 About the App

The Smart Home Controller app is a Flutter-based mobile application that allows you to:
- Control your ESP32-based 4-channel TRIAC smart home controller
- Monitor device states in real-time
- Configure WiFi settings for your controller
- Manage scenes and schedules
- View system information and statistics

## 📦 APK Files

APK files for different versions and build variants will be stored in this directory:

```
app/
├── README.md (this file)
├── release/
│   └── smart-home-controller-v{version}-release.apk
└── debug/
    └── smart-home-controller-v{version}-debug.apk
```

### Current Release

**Latest Version:** 1.0.0

- **Release APK:** Not yet built
- **Debug APK:** Not yet built

## 🛠️ Building the APK

To build the APK from source:

### Prerequisites

1. **Install Flutter SDK**
   ```bash
   # Download from https://flutter.dev/docs/get-started/install
   # Or use a package manager:
   # macOS: brew install flutter
   # Linux: snap install flutter --classic
   ```

2. **Verify Flutter installation**
   ```bash
   flutter doctor
   ```

3. **Install Android SDK and accept licenses**
   ```bash
   flutter doctor --android-licenses
   ```

### Build Steps

1. **Navigate to the Flutter project directory**
   ```bash
   cd "frontend/flutter project/demo"
   ```

2. **Get dependencies**
   ```bash
   flutter pub get
   ```

3. **Build Release APK**
   ```bash
   flutter build apk --release
   ```
   
   The APK will be generated at:
   ```
   frontend/flutter project/demo/build/app/outputs/flutter-apk/app-release.apk
   ```

4. **Build Debug APK (for testing)**
   ```bash
   flutter build apk --debug
   ```

5. **Copy APK to this folder** (from repository root)
   ```bash
   # Return to repository root first
   cd ../../..
   
   # For release build
   cp "frontend/flutter project/demo/build/app/outputs/flutter-apk/app-release.apk" \
      app/release/smart-home-controller-v1.0.0-release.apk
   
   # For debug build
   cp "frontend/flutter project/demo/build/app/outputs/flutter-apk/app-debug.apk" \
      app/debug/smart-home-controller-v1.0.0-debug.apk
   ```
   
   Or from Flutter project directory:
   ```bash
   # For release build (from demo/ directory)
   cp build/app/outputs/flutter-apk/app-release.apk \
      ../../../app/release/smart-home-controller-v1.0.0-release.apk
   
   # For debug build (from demo/ directory)
   cp build/app/outputs/flutter-apk/app-debug.apk \
      ../../../app/debug/smart-home-controller-v1.0.0-debug.apk
   ```

### Build Variants

- **Release APK**: Optimized for production use, smaller size, no debug symbols
  ```bash
  flutter build apk --release
  ```

- **Debug APK**: Includes debug symbols, useful for development
  ```bash
  flutter build apk --debug
  ```

- **Profile APK**: For performance profiling
  ```bash
  flutter build apk --profile
  ```

- **Split APKs by ABI** (reduces size for specific architectures):
  ```bash
  flutter build apk --split-per-abi
  ```
  This generates separate APKs for:
  - `app-armeabi-v7a-release.apk` (32-bit ARM)
  - `app-arm64-v8a-release.apk` (64-bit ARM)
  - `app-x86_64-release.apk` (64-bit Intel)

## 📲 Installing the APK

### On Android Device

1. **Enable Installation from Unknown Sources**
   - Go to Settings → Security
   - Enable "Unknown Sources" or "Install Unknown Apps"

2. **Transfer and Install**
   - Transfer the APK to your device via USB, email, or cloud storage
   - Tap the APK file to install
   - Follow the on-screen prompts

### Using ADB (Android Debug Bridge)

```bash
# Install via ADB
adb install app/release/smart-home-controller-v1.0.0-release.apk

# Install and replace existing version
adb install -r app/release/smart-home-controller-v1.0.0-release.apk

# Uninstall
adb uninstall com.example.demo
```

## 🔐 App Signing

For production releases, APKs should be signed with a release keystore:

1. **Create a keystore** (one-time setup):
   ```bash
   keytool -genkey -v -keystore ~/smarthome-release-key.jks \
           -keyalg RSA -keysize 2048 -validity 10000 \
           -alias smarthome
   ```

2. **Configure signing in Android Studio or create `key.properties`**:
   ```properties
   storePassword=<password>
   keyPassword=<password>
   keyAlias=smarthome
   storeFile=<path-to-keystore>
   ```

3. **Build signed release APK**:
   ```bash
   flutter build apk --release
   ```

## 📝 Version History

### Version 1.0.0 (Initial Release)
- Initial release of Smart Home Controller app
- WiFi configuration interface
- Device control functionality
- Real-time status monitoring
- HTTP and WebSocket communication

## 🐛 Troubleshooting

### Build Issues

**Problem:** `flutter: command not found`
- **Solution:** Install Flutter SDK and add it to your PATH

**Problem:** Android SDK not found
- **Solution:** Run `flutter doctor` and follow instructions to install Android SDK

**Problem:** License errors
- **Solution:** Run `flutter doctor --android-licenses` and accept all licenses

### Installation Issues

**Problem:** "App not installed"
- **Solution:** Uninstall any existing version first, or use `adb install -r`

**Problem:** "Parse error"
- **Solution:** Ensure APK is not corrupted and is compatible with your Android version

## 🔗 Related Documentation

- Flutter Project: `frontend/flutter project/demo/`
- [Firmware Documentation](../firmware/README.md)
- [Installation Guide](../INSTALL.md)
- [Main README](../README.md)

## 📧 Support

For issues or questions:
- Open an issue on [GitHub](https://github.com/Gokul3611/smarthome-controller/issues)
- Check the [project wiki](https://github.com/Gokul3611/smarthome-controller/wiki)

---

**Note:** APK files are typically not committed to Git repositories due to their size. Consider using GitHub Releases or a separate distribution channel for sharing built APKs.

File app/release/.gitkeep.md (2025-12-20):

# Release APK Directory

This directory contains release builds of the Smart Home Controller Android app.

## Naming Convention

Release APKs should follow this naming pattern:
```
smart-home-controller-v{major}.{minor}.{patch}-release.apk
```

Examples:
- `smart-home-controller-v1.0.0-release.apk`
- `smart-home-controller-v1.0.1-release.apk`
- `smart-home-controller-v2.0.0-release.apk`

## Building Release APK

From the Flutter project directory:
```bash
cd "frontend/flutter project/demo"
flutter build apk --release
cp build/app/outputs/flutter-apk/app-release.apk ../../../app/release/smart-home-controller-v1.0.0-release.apk
```

## APK Characteristics

Release APKs are:
- ✅ Optimized for production use
- ✅ Smaller file size
- ✅ Code obfuscation enabled
- ✅ Should be signed with release keystore
- ❌ No debug symbols included
- ❌ Cannot be debugged

## Distribution

Release APKs can be distributed via:
- GitHub Releases
- Direct download links
- App stores (after proper signing)
- Internal distribution platforms

---

**Note:** APK files are not committed to the repository. This directory exists to provide a consistent location for placing built APKs.

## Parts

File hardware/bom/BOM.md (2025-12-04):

# Bill of Materials (BOM)

Complete parts list for building the Smart Home Controller.

## Main Components

| Item | Part Number | Description | Qty | Unit Price | Total | Supplier |
|---|---|---|-----|---|---|---|
| 1 | ESP32-WROOM-32 | WiFi+BT MCU Module | 1 | $5.00 | $5.00 | DigiKey, Mouser |
| 2 | BT136-600E | 4A 600V TRIAC TO-220 | 4 | $0.50 | $2.00 | DigiKey, Mouser |
| 3 | MOC3021 | Random Phase Optocoupler | 4 | $0.40 | $1.60 | DigiKey, Mouser |
| 4 | 4N25 | Optocoupler for Zero-Cross | 1 | $0.30 | $0.30 | DigiKey, Mouser |
| 5 | 1N4007 | 1A 1000V Rectifier Diode | 4 | $0.10 | $0.40 | DigiKey, Mouser |
| 6 | AMS1117-5.0 | 5V 1A Linear Regulator | 1 | $0.50 | $0.50 | DigiKey, Mouser |
| 7 | Transformer | 230V to 12V 2VA | 1 | $3.00 | $3.00 | Local supplier |

## Resistors (1/4W unless noted)

| Value | Description | Qty | Notes |
|---|---|-----|---|
| 100Ω | TRIAC gate resistor (1/2W) | 4 | Must be 1/2W or higher |
| 330Ω | LED current limit | 4 | For optocoupler drive |
| 1kΩ | Zero-cross limiting | 1 | 1/2W recommended |
| 10kΩ | Pull-down/Pull-up | 8 | General purpose |
| 100kΩ | High impedance | 2 | Optional, for RC snubber |

## Capacitors

| Value | Type | Voltage | Qty | Description |
|---|---|---|-----|---|
| 0.1µF | Ceramic | 50V | 8 | Bypass capacitors |
| 0.1µF | Film | 400V | 4 | Snubber capacitors (optional) |
| 10µF | Electrolytic | 16V | 2 | Power supply filtering |
| 100µF | Electrolytic | 16V | 2 | Power supply filtering |
| 1000µF | Electrolytic | 16V | 1 | Main power reservoir |

## Connectors & Terminals

| Item | Description | Qty | Notes |
|---|---|-----|---|
| Screw terminals | 2-position 5mm pitch | 8 | For AC connections |
| Pin headers | 2.54mm pitch | 20 | For ESP32 mounting |
| USB connector | Micro-B or Type-C | 1 | For programming |

## Mechanical Parts

| Item | Description | Qty | Notes |
|---|---|-----|---|
| Heatsink | TO-220 compatible | 4 | For TRIACs |
| Thermal pad | Silicone pad | 4 | Between TRIAC and heatsink |
| Mounting screws | M3 × 6mm | 8 | For heatsinks |
| Standoffs | M3 × 10mm | 4 | For PCB mounting |
| Enclosure | ABS plastic 120×80×40mm | 1 | Non-conductive |

## Optional Components

| Item | Description | Qty | Purpose |
|---|---|-----|---|
| Status LED | 5mm red LED | 1 | Power indicator |
| Tactile switch | 6×6mm | 4 | Physical controls |
| Buzzer | 5V piezo | 1 | Audio feedback |
| Temperature sensor | DS18B20 | 1 | Thermal monitoring |
| Current sensor | ACS712 5A | 4 | Power monitoring |

## Tools & Consumables

| Item | Description | Notes |
|---|---|---|
| Solder | 60/40 or lead-free | ~50g required |
| Flux | Rosin flux pen | For rework |
| Wire | 18AWG stranded | For AC connections |
| Wire | 22-24AWG solid | For DC connections |
| Heat shrink | Assorted sizes | For insulation |
| Cable ties | 100mm | For wire management |

## Cost Summary

| Category | Estimated Cost |
|---|---|
| Electronic Components | $15.00 |
| Connectors & Hardware | $5.00 |
| Enclosure | $8.00 |
| PCB (prototype) | $10.00 |
| Optional Components | $10.00 |
| Tools & Consumables | $15.00 |
| **Total (single unit)** | **$48.00** |
| **Total (10 units)** | **$200.00** |
| **Total (100 units)** | **$1,200.00** |

*Prices approximate, as of December 2024. Bulk pricing available for quantities >10.*

## Supplier Information

### Recommended Suppliers

**International:**
- DigiKey (digikey.com) - Fast shipping, large inventory
- Mouser (mouser.com) - Good for small quantities
- LCSC (lcsc.com) - Low cost, based in China
- Arrow (arrow.com) - Good for professional quantities

**Local (India):**
- Robu.in
- ElectronicsPro.in
- Amazon.in (limited selection)

### Bulk Purchasing

For quantities >50 units:
- Contact manufacturers directly
- Use Alibaba for Chinese suppliers
- Negotiate pricing with local distributors

## Substitutions

### Acceptable Alternatives

| Original Part | Alternative | Notes |
|---|---|---|
| BT136 | BTA16, Q4008L | Similar specs |
| MOC3021 | MOC3041 | 3041 has zero-cross |
| 4N25 | PC817, LTV817 | Any optocoupler |
| ESP32-WROOM-32 | ESP32-WROVER-32 | More RAM |
| AMS1117 | LM1117, LD1117 | Same footprint |

### NOT Recommended

- Don't use SCRs instead of TRIACs (won't work for AC)
- Don't use transistors instead of optocouplers (no isolation)
- Don't use undersized TRIACs (minimum 4A rating)

## Procurement Notes

1. **Order extra components** (10-20% surplus) for prototyping and repairs
2. **Check lead times** - some components may have 4-8 week delivery
3. **Buy from authorized distributors** to avoid counterfeit parts
4. **Keep datasheets** - download and archive for reference
5. **Test components** before assembly (especially TRIACs and optocouplers)

## Quality Control

### Incoming Inspection

For critical components, test:
- [ ] TRIAC forward voltage drop
- [ ] Optocoupler CTR (current transfer ratio)
- [ ] ESP32 basic functionality
- [ ] Power supply output voltage
- [ ] Capacitor ESR (for electrolytics)

## Revision History

| Version | Date | Changes |
|---|---|---|
| 1.0 | Dec 2024 | Initial BOM |

## Notes

- All prices in USD
- Minimum order quantities (MOQ) may apply
- Check local availability and import duties
- Consider lead-free requirements for commercial products
- Add margin for damaged/lost components

---

**Contact**: For BOM questions, open GitHub issue with "BOM:" prefix

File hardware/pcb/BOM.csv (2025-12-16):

Reference | Quantity | Value | Description | Manufacturer | MPN | Package | Supplier | Supplier Part Number | Unit Price | Extended Price
U1 | 1 | ESP32-WROOM-32 | WiFi+BT MCU Module | Espressif | ESP32-WROOM-32 | SMD Module | DigiKey | 1904-1010-1-ND | $5.00 | $5.00
Q1,Q2,Q3,Q4 | 4 | BT136-600E | 4A 600V TRIAC | NXP | BT136-600E | TO-220 | Mouser | 771-BT136-600E | $0.50 | $2.00
U2,U3,U4,U5 | 4 | MOC3021 | Random Phase Optocoupler | Lite-On | MOC3021M | DIP-6 | DigiKey | 160-1366-5-ND | $0.40 | $1.60
U6 | 1 | 4N25 | Optocoupler for Zero-Cross | Vishay | 4N25 | DIP-6 | Mouser | 512-4N25 | $0.30 | $0.30
D1,D2,D3,D4,D5,D6,D7,D8 | 8 | 1N4007 | 1A 1000V Rectifier Diode | ON Semi | 1N4007G | DO-41 | DigiKey | 1N4007GDICT-ND | $0.10 | $0.80
U7 | 1 | AMS1117-5.0 | 5V 1A Linear Regulator | AMS | AMS1117-5.0 | SOT-223 | DigiKey | AMS1117-5.0CT-ND | $0.50 | $0.50
T1 | 1 | Transformer | 230V to 12V 2VA Transformer | Generic | 230V-12V-2VA | PCB Mount | Local Supplier | N/A | $3.00 | $3.00
R1,R2,R3,R4 | 4 | 330Ω | LED Current Limit 1/4W | Yageo | CFR-25JB-52-330R | Axial 1/4W | DigiKey | 330QBK-ND | $0.02 | $0.08
R5,R6,R7,R8 | 4 | 100Ω | TRIAC Gate Resistor 1/2W | Yageo | MFR-25FBF52-100R | Axial 1/2W | DigiKey | 100W-1-ND | $0.05 | $0.20
R9 | 1 | 1kΩ | Zero-Cross Limiting 1/2W | Yageo | MFR-25FBF52-1K | Axial 1/2W | DigiKey | 1.0KQBK-ND | $0.05 | $0.05
R10,R11,R12,R13,R14,R15,R16,R17 | 8 | 10kΩ | Pull-down/Pull-up 1/4W | Yageo | CFR-25JB-52-10K | Axial 1/4W | DigiKey | 10KQBK-ND | $0.02 | $0.16
R18,R19 | 2 | 100kΩ | High Impedance 1/4W | Yageo | CFR-25JB-52-100K | Axial 1/4W | DigiKey | 100KQBK-ND | $0.02 | $0.04
C1,C2,C3,C4,C5,C6,C7,C8 | 8 | 0.1µF | Bypass Capacitor 50V | Kemet | C320C104K5R5TA | Ceramic Disc | DigiKey | 399-4151-ND | $0.10 | $0.80
C9,C10,C11,C12 | 4 | 0.1µF | Snubber Capacitor 400V X2 | EPCOS | B32922C3104M | Film Capacitor | Mouser | 871-B32922C3104M | $0.30 | $1.20
C13,C14 | 2 | 10µF | Power Filter 16V | Nichicon | UVR1C100MDD | Electrolytic 5mm | DigiKey | 493-2203-ND | $0.15 | $0.30
C15,C16 | 2 | 100µF | Power Filter 16V | Nichicon | UVR1C101MDD | Electrolytic 6.3mm | DigiKey | 493-2206-ND | $0.20 | $0.40
C17 | 1 | 1000µF | Main Reservoir 16V | Nichicon | UVR1C102MHD | Electrolytic 10mm | DigiKey | 493-2215-ND | $0.50 | $0.50
J1,J2 | 2 | Screw Terminal | 2-pos 5mm AC Input | Phoenix | 1757019 | 5mm Pitch | DigiKey | 277-1667-ND | $0.40 | $0.80
J3,J4,J5,J6 | 4 | Screw Terminal | 2-pos 5mm AC Output | Phoenix | 1757019 | 5mm Pitch | DigiKey | 277-1667-ND | $0.40 | $1.60
J7 | 1 | Pin Header | 2x19 2.54mm Female | Sullins | PPPC192LFBN-RC | 2.54mm Pitch | DigiKey | S7118-ND | $1.00 | $1.00
J8 | 1 | USB Connector | Micro-B USB | Molex | 47346-0001 | SMD | DigiKey | WM17117CT-ND | $0.50 | $0.50
SW1,SW2,SW3,SW4 | 4 | Tactile Switch | 6x6mm Tactile Button | Omron | B3F-1000 | Through-hole | DigiKey | SW400-ND | $0.20 | $0.80
F1 | 1 | Fuse | 2A Slow-Blow 250V | Littelfuse | 0215002.MXP | 5x20mm | DigiKey | F2416-ND | $0.30 | $0.30
F2 | 1 | Fuse Holder | 5x20mm PCB Mount | Keystone | 3568 | Through-hole | DigiKey | 36-3568-ND | $0.50 | $0.50
HS1,HS2,HS3,HS4 | 4 | Heatsink | TO-220 Heatsink | Aavid | 577102B00000G | TO-220 | Mouser | 532-577102B00 | $0.60 | $2.40
LED1 | 1 | LED | 5mm Red LED | Kingbright | WP7113SRD | Through-hole 5mm | DigiKey | 754-1217-ND | $0.10 | $0.10
 |  |  |  |  |  |  |  | Subtotal: | $24.93
 |  |  |  |  |  |  |  | PCB (5pcs): | $10.00
 |  |  |  |  |  |  |  | Shipping: | $5.00
 |  |  |  |  |  |  |  | Total (single unit): | $39.93
 |  |  |  |  |  |  |  | Total (10 units): | $259.30
 |  |  |  |  |  |  |  | Total (100 units): | $2 | 093.00

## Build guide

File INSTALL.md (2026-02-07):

# Installation & Setup Guide

Complete guide for installing and configuring the Smart Home Controller firmware.

## Table of Contents

1. [Prerequisites](#prerequisites)
2. [Hardware Setup](#hardware-setup)
3. [Software Installation](#software-installation)
4. [Firmware Upload](#firmware-upload)
5. [Initial Configuration](#initial-configuration)
6. [Google Apps Script Setup](#google-apps-script-setup)
7. [Voice Assistant Setup](#voice-assistant-setup)
8. [Flutter App Integration](#flutter-app-integration)
9. [Troubleshooting](#troubleshooting)

## Prerequisites

### Hardware Requirements

- ESP32 development board (WROOM-32 or compatible)
- 4-channel TRIAC controller board
- Zero-cross detection circuit
- 5V power supply (2A minimum)
- USB cable for programming

### Software Requirements

- Arduino IDE 2.x or PlatformIO
- USB-to-UART drivers for ESP32
- Google Apps Script account (free)
- WiFi network (2.4GHz)

## Hardware Setup

### Pin Connections

Connect your ESP32 to the TRIAC controller as follows:

| ESP32 Pin | Function | Connection |
|---|---|---|
| GPIO 13 | Zero-Cross Input | Connect to ZC detector output |
| GPIO 16 | TRIAC 1 Control | Connect to TRIAC 1 optocoupler |
| GPIO 17 | TRIAC 2 Control | Connect to TRIAC 2 optocoupler |
| GPIO 18 | TRIAC 3 Control | Connect to TRIAC 3 optocoupler |
| GPIO 19 | TRIAC 4 Control | Connect to TRIAC 4 optocoupler |
| GPIO 32 | Switch 1 | Physical button with pull-up |
| GPIO 33 | Switch 2 | Physical button with pull-up |
| GPIO 25 | Switch 3 | Physical button with pull-up |
| GPIO 26 | Switch 4 | Physical button with pull-up |
| 5V | Power | 5V power supply |
| GND | Ground | Common ground |

### Safety Warnings

⚠️ **HIGH VOLTAGE WARNING** ⚠️

- TRIAC circuits handle mains voltage (110-240V AC)
- Always disconnect power before working on circuits
- Use proper isolation and safety measures
- Have a qualified electrician review your setup
- Test with low voltage loads first

## Software Installation

### Option 1: Arduino IDE (Recommended for beginners)

1. **Install Arduino IDE**
   - Download from [arduino.cc](https://www.arduino.cc/en/software)
   - Install version 2.0 or later

2. **Add ESP32 Board Support**
   - Open Arduino IDE
   - Go to File → Preferences
   - Add to "Additional Board Manager URLs":
     ```
     https://raw.githubusercontent.com/espressif/arduino-esp32/gh-pages/package_esp32_index.json
     ```
   - Go to Tools → Board → Boards Manager
   - Search for "esp32"
   - Install "esp32 by Espressif Systems" (version 2.0.x or later)

3. **Install Required Libraries**
   - Go to Tools → Manage Libraries
   - Install the following libraries:
     - **WiFiManager** by tzapu (v2.0.16 or later)
     - **ArduinoJson** by Benoit Blanchon (v6.x - NOT v7)
     - **Espalexa** by Christian Schwinne (v2.7.0 or later)
     - **WebSockets** by Markus Sattler (v2.4.0 or later)
     - **SinricPro** (optional, for Google Assistant)

### Option 2: PlatformIO (Recommended for advanced users)

1. **Install VS Code**
   - Download from [code.visualstudio.com](https://code.visualstudio.com/)

2. **Install PlatformIO Extension**
   - Open VS Code
   - Go to Extensions (Ctrl+Shift+X)
   - Search for "PlatformIO IDE"
   - Click Install

3. **Create Project**
   ```bash
   cd smarthome-controller/firmware
   pio init -b esp32dev
   ```

4. **Configure platformio.ini**
   ```ini
   [env:esp32dev]
   platform = espressif32
   board = esp32dev
   framework = arduino
   monitor_speed = 115200
   
   lib_deps = 
       tzapu/WiFiManager@^2.0.16
       bblanchon/ArduinoJson@^6.21.3
       vintlabs/Fauxmo ESP@^3.4
       links2004/WebSockets@^2.4.0
       sinricpro/SinricPro@^2.10.0
   ```

## Firmware Upload

### Using Arduino IDE

1. **Open the Firmware**
   - Navigate to `smarthome-controller/firmware/main/`
   - Open `main.ino` in Arduino IDE

2. **Configure Board Settings**
   - Tools → Board → ESP32 Arduino → ESP32 Dev Module
   - Tools → Flash Size → 4MB (32Mb)
   - Tools → Partition Scheme → Default 4MB with spiffs
   - Tools → Upload Speed → 921600
   - Tools → CPU Frequency → 240MHz

3. **Configure Google Apps Script URL** (Before Upload)
   - Open `main.ino`
   - Find the line:
     ```cpp
     String GOOGLE_SCRIPT_URL = "your_url_here";
     ```
   - Replace with your Google Apps Script URL (see section below)

4. **Upload**
   - Connect ESP32 via USB
   - Select the correct COM port (Tools → Port)
   - Click Upload button (→)
   - Wait for upload to complete

### Using PlatformIO

```bash
# Build firmware
pio run

# Upload firmware
pio run --target upload

# Monitor serial output
pio device monitor
```

## Initial Configuration

### First Boot Setup

1. **Power On**
   - Power the ESP32
   - Wait 10-15 seconds for boot

2. **Connect to WiFi Portal**
   - On your phone/computer, connect to WiFi network: `Smart_Home_Hub`
   - Browser should automatically open to configuration page
   - If not, navigate to: `http://192.168.4.1`

3. **Configure WiFi**
   - Click "Scan networks"
   - Select your WiFi network from the list
   - Enter WiFi password
   - Click "Save & Connect"
   - Device will reboot and connect to your network

4. **Find Device IP**
   - Check your router's DHCP client list
   - Or use mDNS: `http://smart-home-hub.local` (Mac/Linux)
   - Or check Serial Monitor at 115200 baud for IP address

### Factory Reset

If you need to reset the device:

1. Hold Switch 1 (GPIO 32) for 10 seconds
2. Device will erase all settings and reboot
3. Follow "First Boot Setup" again

## Google Apps Script Setup

### Create Apps Script

1. **Open Google Apps Script**
   - Go to [script.google.com](https://script.google.com)
   - Click "New Project"

2. **Add Script Code**

```javascript
function doPost(e) {
  try {
    var data = JSON.parse(e.postData.contents);
    
    // Log incoming data
    Logger.log('Received: ' + JSON.stringify(data));
    
    // Store device state in Properties Service
    var props = PropertiesService.getScriptProperties();
    props.setProperty(data.uid, JSON.stringify(data));
    
    // Prepare response
    var response = {
      sys_name: "Living Room Hub",
      ota_update: false,
      bin_url: "",
      d1: {
        type: "FAN",
        name: "Ceiling Fan",
        lock: false,
        update: false,
        state: 0,
        val: 100
      },
      d2: {
        type: "SWITCH",
        name: "Light",
        lock: false,
        update: false,
        state: 0,
        val: 100
      },
      d3: {
        type: "DIMMER",
        name: "Lamp",
        lock: false,
        update: false,
        state: 0,
        val: 100
      },
      d4: {
        type: "SWITCH",
        name: "Outlet",
        lock: false,
        update: false,
        state: 0,
        val: 100
      }
    };
    
    return ContentService.createTextOutput(JSON.stringify(response))
      .setMimeType(ContentService.MimeType.JSON);
      
  } catch (error) {
    Logger.log('Error: ' + error.toString());
    return ContentService.createTextOutput(JSON.stringify({error: error.toString()}))
      .setMimeType(ContentService.MimeType.JSON);
  }
}

function doGet(e) {
  return HtmlService.createHtmlOutput('<h1>Smart Home Controller API</h1>');
}
```

3. **Deploy**
   - Click Deploy → New deployment
   - Type: Web app
   - Execute as: Me
   - Who has access: Anyone
   - Click Deploy
   - Copy the Web app URL

4. **Update Firmware**
   - Paste the URL into `GOOGLE_SCRIPT_URL` in `main.ino`
   - Re-upload firmware OR
   - Update via OTA (if already running)

## Voice Assistant Setup

### Amazon Alexa

1. **Ensure Same Network**
   - ESP32 and Alexa device must be on same WiFi network

2. **Discover Devices**
   - Open Alexa app
   - Go to Devices → Add Device
   - Select "Other"
   - Click "Discover Devices"
   - Wait for discovery (30-45 seconds)

3. **Control Devices**
   - "Alexa, turn on Device 1"
   - "Alexa, set Ceiling Fan to 50%"
   - "Alexa, turn off all devices"

### Google Assistant (via SinricPro)

1. **Create SinricPro Account**
   - Go to [sinric.pro](https://sinric.pro)
   - Sign up for free account

2. **Add Devices**
   - Dashboard → Devices → Add Device
   - Select device type (Switch, Dimmer, Fan, etc.)
   - Create 4 devices for your 4 channels
   - Copy Device IDs

3. **Get Credentials**
   - Go to Credentials
   - Copy App Key and App Secret

4. **Configure in Google Apps Script**
   - Update your Apps Script to return:
     ```javascript
     {
       sinric_key: "your_app_key",
       sinric_secret: "your_app_secret"
     }
     ```

5. **Link Google Assistant**
   - Open Google Home app
   - Add device → Works with Google
   - Search for "Smart Home"
   - Link your SinricPro account
   - Discover devices

6. **Control via Google**
   - "Hey Google, turn on the fan"
   - "Hey Google, set living room light to 30%"

## Flutter App Integration

### Local Control API

The device exposes a REST API on port 8080:

```bash
# Get device status
curl http://192.168.1.100:8080/status

# Control device
curl -X POST http://192.168.1.100:8080/control \
  -H "Content-Type: application/json" \
  -d '{"id": 0, "state": true, "brightness": 75}'

# Get system info
curl http://192.168.1.100:8080/info
```

### WebSocket Real-Time Updates

Connect to `ws://192.168.1.100:81` for real-time device state updates.

Example (JavaScript):
```javascript
const ws = new WebSocket('ws://192.168.1.100:81');

ws.onmessage = (event) => {
  const data = JSON.parse(event.data);
  console.log('Device update:', data);
};
```

## Troubleshooting

### Device Won't Boot

- Check power supply (5V, 2A minimum)
- Check USB cable and connections
- Try factory reset
- Re-upload firmware with "Erase All Flash" option

### WiFi Won't Connect

- Ensure 2.4GHz network (5GHz not supported)
- Check signal strength (need >-80 dBm)
- Try factory reset and reconfigure
- Check router MAC filtering / DHCP settings

### Voice Control Not Working

**Alexa:**
- Ensure same WiFi network
- Restart Alexa device
- Delete and rediscover devices
- Check mDNS is working

**Google Assistant:**
- Verify SinricPro credentials
- Check cloud connection status
- Unlink and relink account
- Check SinricPro dashboard for device status

### OTA Update Failed

- Ensure stable internet connection
- Check firmware binary URL is accessible
- Verify sufficient flash space (need >1MB free)
- Try upload via USB instead

### TRIAC Control Not Working

- Verify zero-cross signal with oscilloscope
- Check optocoupler connections
- Test with multimeter (AC voltage present)
- Ensure proper TRIAC ratings for load
- Check for loose connections

### Serial Monitor Shows Errors

Common error messages:

- `Zero-cross signal lost`: Check ZC detector circuit
- `WiFi disconnected`: Check network stability
- `Cloud sync failed`: Check Google Apps Script URL
- `Memory low`: Reduce LOG_LEVEL or restart device

## Advanced Configuration

### Custom Configuration

Edit `config.h` to customize:

- Pin assignments
- Timing parameters
- Safety timeouts
- Log levels
- Buffer sizes

### Compile-Time Options

Add to Arduino IDE or `platformio.ini`:

```cpp
// Enable verbose debugging
-DLOG_LEVEL=LOG_DEBUG

// Increase stack sizes
-DCONFIG_ARDUINO_LOOP_STACK_SIZE=16384

// Enable PSRAM (if available)
-DBOARD_HAS_PSRAM
```

## Support

- GitHub Issues: [github.com/Gokul3611/smarthome-controller/issues](https://github.com/Gokul3611/smarthome-controller/issues)
- Documentation: See README.md

---

**Last Updated:** December 2024
**Firmware Version:** 3.0

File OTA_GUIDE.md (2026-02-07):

# OTA (Over-The-Air) Update Guide

Complete guide for implementing and using OTA firmware updates for the Smart Home Controller.

---

## Overview

OTA updates allow you to update ESP32 firmware remotely without physical access to the device. This is essential for:
- Bug fixes and security patches
- New feature deployment
- Configuration updates
- Emergency fixes

---

## System Architecture

```
Developer → GitHub Release → Google Apps Script → ESP32 Device
              (Binary)         (Distribution)      (Downloads & Installs)
```

### Update Flow

1. **Compile** new firmware binary (.bin file)
2. **Upload** to hosting (GitHub Releases, Google Drive, or Apps Script)
3. **Configure** backend to signal update availability
4. **ESP32 polls** backend, detects update
5. **Download** firmware binary
6. **Verify** checksum/signature
7. **Install** to OTA partition
8. **Reboot** and test
9. **Rollback** if boot fails (automatic)

---

## ESP32 OTA Implementation

### 1. Partition Scheme

ESP32 requires special partition layout for OTA:

```
# partitions.csv
Name,     Type, SubType, Offset,  Size
nvs,      data, nvs,     0x9000,  0x5000
otadata,  data, ota,     0xe000,  0x2000
app0,     app,  ota_0,   0x10000, 0x140000
app1,     app,  ota_1,   0x150000,0x140000
spiffs,   data, spiffs,  0x290000,0x70000
```

**Key Points:**
- `app0` and `app1` are two firmware slots
- System alternates between them
- Failed boot automatically rolls back

### 2. Arduino Code

Add to your ESP32 firmware:

```cpp
#include <Update.h>
#include <HTTPClient.h>
#include <WiFiClientSecure.h>

// OTA Configuration
const char* OTA_URL = "https://your-backend/firmware.bin";
const String CURRENT_VERSION = "3.0.0";

void checkForUpdates() {
  HTTPClient http;
  WiFiClientSecure client;
  client.setInsecure(); // For testing only! Use proper certificate in production
  
  // Check if update available
  String checkUrl = GOOGLE_SCRIPT_URL + "?action=check_ota&current_version=" + CURRENT_VERSION;
  http.begin(client, checkUrl);
  
  int httpCode = http.GET();
  if (httpCode == 200) {
    String payload = http.getString();
    DynamicJsonDocument doc(1024);
    deserializeJson(doc, payload);
    
    if (doc["update_available"].as<bool>()) {
      String binUrl = doc["bin_url"].as<String>();
      String newVersion = doc["version"].as<String>();
      
      Serial.println("Update available: " + newVersion);
      performOTAUpdate(binUrl);
    }
  }
  http.end();
}

void performOTAUpdate(String binUrl) {
  HTTPClient http;
  WiFiClientSecure client;
  client.setInsecure();
  
  Serial.println("Starting OTA update from: " + binUrl);
  http.begin(client, binUrl);
  
  int httpCode = http.GET();
  if (httpCode == 200) {
    int contentLength = http.getSize();
    bool canBegin = Update.begin(contentLength);
    
    if (canBegin) {
      WiFiClient * stream = http.getStreamPtr();
      size_t written = Update.writeStream(*stream);
      
      if (written == contentLength) {
        Serial.println("Written : " + String(written) + " successfully");
      } else {
        Serial.println("Written only : " + String(written) + "/" + String(contentLength));
      }
      
      if (Update.end()) {
        Serial.println("OTA done!");
        if (Update.isFinished()) {
          Serial.println("Update successfully completed. Rebooting...");
          delay(1000);
          ESP.restart();
        } else {
          Serial.println("Update not finished? Something went wrong!");
        }
      } else {
        Serial.println("Error Occurred. Error #: " + String(Update.getError()));
      }
    } else {
      Serial.println("Not enough space to begin OTA");
    }
  }
  http.end();
}

// Call in loop() or use timer
void loop() {
  // Check for updates every 24 hours
  static unsigned long lastCheck = 0;
  if (millis() - lastCheck > 86400000) { // 24 hours
    checkForUpdates();
    lastCheck = millis();
  }
  
  // ... rest of your code
}
```

### 3. Build Firmware Binary

**Using Arduino IDE:**
```
1. Sketch → Export Compiled Binary
2. Find .bin file in build folder
3. File name: firmware_v3.0.0.bin
```

**Using PlatformIO:**
```bash
pio run
# Binary at: .pio/build/esp32dev/firmware.bin
```

**Using ESP-IDF:**
```bash
idf.py build
# Binary at: build/project_name.bin
```

---

## Backend OTA Configuration

### Google Apps Script Implementation

Add to `Code.gs`:

```javascript
/**
 * Check for OTA updates
 */
function handleCheckOTA(data) {
  const currentVersion = data.current_version;
  const latestVersion = "3.0.1"; // Update this when new version available
  const binUrl = "https://github.com/Gokul3611/smarthome-controller/releases/download/v3.0.1/firmware.bin";
  
  const updateAvailable = compareVersions(latestVersion, currentVersion) > 0;
  
  return jsonResponse({
    success: true,
    update_available: updateAvailable,
    version: latestVersion,
    bin_url: binUrl,
    changelog: "Bug fixes and improvements",
    mandatory: false,
    release_notes_url: "https://github.com/Gokul3611/smarthome-controller/releases/latest"
  });
}

/**
 * Compare semantic versions
 */
function compareVersions(v1, v2) {
  const parts1 = v1.split('.').map(Number);
  const parts2 = v2.split('.').map(Number);
  
  for (let i = 0; i < 3; i++) {
    if (parts1[i] > parts2[i]) return 1;
    if (parts1[i] < parts2[i]) return -1;
  }
  return 0;
}
```

---

## Hosting Firmware Binaries

### Option 1: GitHub Releases (Recommended)

**Advantages:**
- Free
- Reliable
- Version controlled
- Public or private repos

**Steps:**
1. Create new release on GitHub
2. Tag with version (e.g., v3.0.1)
3. Upload firmware.bin file
4. Get download URL
5. Configure backend with URL

**URL Format:**
```
https://github.com/USER/REPO/releases/download/v3.0.1/firmware.bin
```

### Option 2: Google Drive

**Advantages:**
- Free 15GB storage
- Easy to manage
- Works with Apps Script

**Steps:**
1. Upload firmware.bin to Google Drive
2. Get shareable link
3. Convert to direct download link:
```
Original: https://drive.google.com/file/d/FILE_ID/view
Direct: https://drive.google.com/uc?export=download&id=FILE_ID
```

### Option 3: Apps Script as Host

**Advantages:**
- Same infrastructure as backend
- Integrated

**Limitations:**
- 50MB file size limit
- Bandwidth quotas

**Implementation:**
```javascript
// In Apps Script
function doGet(e) {
  if (e.parameter.file === 'firmware') {
    const blob = DriveApp.getFileById('YOUR_FILE_ID').getBlob();
    return ContentService.createTextOutput(blob.getBytes())
      .setMimeType(ContentService.MimeType.BINARY);
  }
}
```

---

## Security Best Practices

### 1. Firmware Signing

Generate signature for firmware:

```bash
# Generate SHA256 hash
sha256sum firmware.bin > firmware.bin.sha256

# Or use openssl
openssl dgst -sha256 firmware.bin
```

Include in update check:
```javascript
{
  "bin_url": "...",
  "checksum": "abc123...",
  "signature": "def456..."
}
```

Verify in ESP32:
```cpp
#include <mbedtls/md.h>

bool verifyChecksum(uint8_t* data, size_t len, const char* expectedHash) {
  byte hash[32];
  mbedtls_md_context_t ctx;
  
  mbedtls_md_init(&ctx);
  mbedtls_md_setup(&ctx, mbedtls_md_info_from_type(MBEDTLS_MD_SHA256), 0);
  mbedtls_md_starts(&ctx);
  mbedtls_md_update(&ctx, data, len);
  mbedtls_md_finish(&ctx, hash);
  mbedtls_md_free(&ctx);
  
  // Compare hash with expectedHash
  // Return true if match
}
```

### 2. HTTPS Only

Always use HTTPS for firmware downloads:
```cpp
WiFiClientSecure client;
client.setCACert(root_ca); // Production: use proper certificate
```

### 3. Version Control

Implement strict version checking:
```cpp
bool isNewerVersion(String current, String available) {
  // Parse and compare semantic versions
  // Only allow upgrades, not downgrades (unless forced)
}
```

### 4. Rollback Protection

Firmware should mark itself as valid:
```cpp
void setup() {
  // After successful boot
  if (Update.canRollBack()) {
    Update.rollBack(); // Only if boot fails
  }
  
  // Mark this version as good
  // (implement your own logic)
}
```

---

## Dashboard OTA Management

Add to dashboard:

```html
<div class="ota-section">
  <h3>Firmware Updates</h3>
  <p>Current Version: <span id="currentVersion">3.0.0</span></p>
  <p>Latest Version: <span id="latestVersion">3.0.1</span></p>
  <button onclick="triggerOTA()">Update All Devices</button>
</div>

<script>
async function triggerOTA() {
  const confirm = window.confirm('Update all devices? This may take a few minutes.');
  if (!confirm) return;
  
  // Signal backend to mark update as available
  await fetch(API_URL, {
    method: 'POST',
    body: JSON.stringify({
      action: 'trigger_ota',
      version: '3.0.1',
      bin_url: 'https://...'
    })
  });
  
  alert('Update triggered. Devices will update on next poll.');
}
</script>
```

---

## Testing OTA Updates

### Test Procedure

1. **Prepare Test Device**
   - Flash current firmware via USB
   - Connect to WiFi
   - Note current version

2. **Prepare Update**
   - Make small change (e.g., LED blink pattern)
   - Increment version number
   - Build binary

3. **Upload Binary**
   - Upload to GitHub/Drive
   - Get URL
   - Update backend configuration

4. **Trigger Update**
   - Force device to check for updates
   - Monitor serial output
   - Watch for download progress

5. **Verify**
   - Device should reboot
   - Check new version
   - Test functionality

6. **Test Rollback**
   - Upload corrupted binary
   - Device should detect and rollback
   - Should boot to previous version

### Monitoring

Add logging:
```cpp
Serial.println("=== OTA UPDATE LOG ===");
Serial.printf("Current: %s\n", CURRENT_VERSION);
Serial.printf("Available: %s\n", newVersion.c_str());
Serial.printf("URL: %s\n", binUrl.c_str());
Serial.printf("Size: %d bytes\n", contentLength);
Serial.printf("Progress: %d%%\n", (written * 100) / contentLength);
Serial.println("======================");
```

---

## Troubleshooting

### Issue: Update Fails to Download

**Causes:**
- Poor WiFi signal
- Firewall blocking
- URL incorrect
- File too large

**Solutions:**
- Check signal strength (RSSI > -70dBm)
- Test URL in browser
- Reduce binary size
- Retry with exponential backoff

### Issue: Update Downloaded but Won't Install

**Causes:**
- Not enough space
- Corrupted download
- Wrong partition scheme

**Solutions:**
- Check partition table
- Verify checksum
- Clear OTA partition

### Issue: Device Boots but Functions Wrong

**Causes:**
- Configuration mismatch
- Library version changes
- EEPROM format changed

**Solutions:**
- Preserve configuration during update
- Migrate settings if needed
- Test thoroughly before deployment

### Issue: Device Won't Boot After Update

**Causes:**
- Corrupted firmware
- Wrong ESP32 variant
- Missing bootloader

**Solutions:**
- Rollback should happen automatically
- If not, flash via USB
- Check partition table

---

## OTA Update Statistics

Track in Google Sheets:

| Device UID | Current Version | Update Time | Success | Error |
|---|---|---|---|---|
| AA:BB:CC... | 3.0.0 → 3.0.1 | 2024-12-04 10:30 | ✅ | - |
| DD:EE:FF... | 3.0.0 → 3.0.1 | 2024-12-04 10:35 | ❌ | Download failed |

---

## Best Practices

1. **Test First**: Always test on one device before mass rollout
2. **Gradual Rollout**: Update 10% → 50% → 100% over time
3. **Monitor**: Watch for errors and rollbacks
4. **Backup**: Keep previous firmware version available
5. **Changelog**: Document all changes
6. **Version Scheme**: Use semantic versioning (MAJOR.MINOR.PATCH)
7. **Mandatory vs Optional**: Mark critical security updates as mandatory
8. **Maintenance Window**: Schedule updates during low-usage periods
9. **Notification**: Alert users before major updates
10. **Rollback Plan**: Always have a way to revert

---

## Support

For OTA issues:
- Check ESP32 serial output
- Review backend logs
- Test binary locally first
- Open GitHub issue

---

**Version**: 1.0  
**Last Updated**: December 2024  
**Status**: Production Ready

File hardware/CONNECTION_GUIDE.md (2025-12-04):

# Connection Guide - Smart Home Controller

Complete step-by-step guide for hardware connections and setup.

---

## ⚠️ SAFETY FIRST

**DANGER: HIGH VOLTAGE**

This project involves mains AC voltage which can be **LETHAL**. Follow these safety rules:

1. ✅ **Always disconnect power** before making connections
2. ✅ **Use insulated tools** and work on non-conductive surface
3. ✅ **Double-check all connections** before applying power
4. ✅ **Use proper gauge wires** (minimum 18 AWG for loads)
5. ✅ **Never touch live circuits** - wait 5 minutes after power off
6. ✅ **Have someone nearby** when testing with mains voltage
7. ✅ **Use GFCI/RCD protection** on the AC supply
8. ✅ **Wear safety glasses** when working

**If unsure, consult a licensed electrician.**

---

## 📦 Required Materials

### Components (per channel)

- [ ] ESP32-WROOM-32 development board
- [ ] BT136 TRIAC (or equivalent 4A/600V)
- [ ] MOC3021 or MOC3041 optocoupler
- [ ] 330Ω resistor (1/4W) - for ESP32 to optocoupler
- [ ] 100Ω resistor (1/2W) - for TRIAC gate
- [ ] 10kΩ resistor (1/4W) - pull-down for zero-cross
- [ ] 0.1µF ceramic capacitor
- [ ] Heatsink for TRIAC (TO-220)
- [ ] Screw terminal blocks
- [ ] Enclosure (non-conductive)

### Zero-Cross Detection

- [ ] 230V to 12V AC transformer (or voltage divider)
- [ ] 1N4007 diodes (x4) - bridge rectifier
- [ ] 4N25 optocoupler
- [ ] 1kΩ and 10kΩ resistors

### Power Supply

- [ ] 5V 2A power supply (isolated)
- [ ] AMS1117-3.3 regulator (if not on ESP32 board)
- [ ] Electrolytic capacitors (100µF, 10µF)

### Tools

- [ ] Soldering iron and solder
- [ ] Wire strippers
- [ ] Multimeter
- [ ] Screwdrivers
- [ ] Heat shrink tubing
- [ ] Cable ties

---

## 🔧 Step 1: Zero-Cross Detection Circuit

### Circuit Diagram

```
AC Mains → [Fuse 1A] → Step-down Transformer (230V to 12V AC)
                              ↓
                    Bridge Rectifier (1N4007 x4)
                              ↓
                         [1kΩ Resistor]
                              ↓
                    4N25 Optocoupler (pins 1,2)
                              ↓
                         [10kΩ to GND]
                              ↓
                    4N25 Output (pins 4,5) → ESP32 GPIO13
```

### Connections

1. **AC Input**:
   ```
   Mains Live → Fuse (1A) → Transformer Primary
   Mains Neutral → Transformer Primary
   ```

2. **Bridge Rectifier**:
   ```
   Transformer Secondary (AC) → Bridge Rectifier Input
   Bridge (+) → 1kΩ resistor → 4N25 pin 1 (anode)
   Bridge (-) → 4N25 pin 2 (cathode)
   ```

3. **Optocoupler Output**:
   ```
   4N25 pin 5 → ESP32 3.3V
   4N25 pin 4 → ESP32 GPIO13
   10kΩ resistor → GPIO13 to GND (pull-down)
   ```

### Testing Zero-Cross

1. Power the circuit (no ESP32 yet)
2. Use oscilloscope on 4N25 pin 4
3. Should see pulses at 100Hz (50Hz mains) or 120Hz (60Hz mains)
4. Pulse width: ~1-2ms

---

## 🔧 Step 2: TRIAC Driver Circuit (Per Channel)

### Circuit Diagram (for one channel)

```
ESP32 GPIO16 → [330Ω] → MOC3021 pin 1 (anode)
ESP32 GND → MOC3021 pin 2 (cathode)

MOC3021 pin 6 → [100Ω] → TRIAC Gate
MOC3021 pin 4 → TRIAC MT1

TRIAC MT2 → Load → AC Neutral
AC Live → TRIAC MT1
```

### Detailed Connections

#### For Channel 1 (Repeat for channels 2-4)

1. **ESP32 to Optocoupler**:
   ```
   ESP32 GPIO16 → 330Ω resistor → MOC3021 pin 1
   ESP32 GND → MOC3021 pin 2
   ```

2. **Optocoupler to TRIAC**:
   ```
   MOC3021 pin 6 → 100Ω resistor → BT136 Gate
   MOC3021 pin 4 → BT136 MT1
   ```

3. **TRIAC to Load** (HIGH VOLTAGE):
   ```
   AC Live Wire → BT136 MT1
   BT136 MT2 → Load (Light/Fan)
   Load → AC Neutral
   ```

4. **Add Snubber Circuit** (optional but recommended):
   ```
   Between MT1 and MT2:
   - 100Ω resistor (2W) in series with 0.1µF (400V) capacitor
   ```

### Pin Numbering

**MOC3021 (DIP-6)**:
```
  1 [●]   6  ← Pin 1 has dot/notch
  2       5
  3       4
```

**BT136 (TO-220)**:
```
Looking at flat face with legs down:
Left: MT1
Center: MT2 (to heatsink)
Right: Gate
```

---

## 🔧 Step 3: Physical Switches

Connect tactile switches to ESP32:

```
Switch 1: GPIO32 to GND (internal pull-up enabled)
Switch 2: GPIO33 to GND (internal pull-up enabled)
Switch 3: GPIO25 to GND (internal pull-up enabled)
Switch 4: GPIO26 to GND (internal pull-up enabled)
```

### Optional: Add debounce capacitors

```
Each switch pin: 0.1µF capacitor to GND
```

---

## 🔧 Step 4: Power Supply

### Using External 5V Supply

1. Connect 5V supply positive to ESP32 VIN (or 5V pin)
2. Connect 5V supply ground to ESP32 GND
3. **IMPORTANT**: Ensure power supply is isolated from AC mains

### Using On-Board Regulation

If using transformer:
```
12V AC → Bridge Rectifier → 7805 Regulator → 5V to ESP32
                           ↓
                    Capacitors (100µF input, 10µF output)
```

---

## 🔧 Step 5: Complete Wiring Diagram

### Low Voltage Side (ESP32)

```
ESP32 Pin Connections:
├── GPIO13 ← Zero-Cross Detection (from 4N25 pin 4)
├── GPIO16 → Channel 1 Optocoupler (MOC3021 pin 1)
├── GPIO17 → Channel 2 Optocoupler (MOC3021 pin 1)
├── GPIO18 → Channel 3 Optocoupler (MOC3021 pin 1)
├── GPIO19 → Channel 4 Optocoupler (MOC3021 pin 1)
├── GPIO32 ← Physical Switch 1
├── GPIO33 ← Physical Switch 2
├── GPIO25 ← Physical Switch 3
├── GPIO26 ← Physical Switch 4
├── 5V ← Power Supply (+)
└── GND → All grounds (common)
```

### High Voltage Side (AC)

```
AC Live Wire:
├── Fuse (10A) → Common connection
    ├── TRIAC1 MT1 → Load1 → Neutral
    ├── TRIAC2 MT1 → Load2 → Neutral
    ├── TRIAC3 MT1 → Load3 → Neutral
    └── TRIAC4 MT1 → Load4 → Neutral
```

---

## 🧪 Testing Procedure

### Step 1: Visual Inspection

- [ ] Check all solder joints
- [ ] Verify no shorts between high and low voltage
- [ ] Confirm proper wire gauge
- [ ] Check polarity of electrolytic capacitors
- [ ] Verify TRIAC orientation

### Step 2: Continuity Tests (Power OFF)

- [ ] Test ground continuity
- [ ] Verify isolation between AC and DC (should be infinite)
- [ ] Check switch continuity

### Step 3: Low Voltage Testing

1. Power ESP32 with 5V USB (no AC connected)
2. Flash test firmware
3. Verify GPIO outputs toggle
4. Check zero-cross detection with function generator (simulate AC)

### Step 4: AC Testing (CAREFUL!)

**Use isolation transformer and current limiter for first test**

1. Connect 12V AC to zero-cross circuit first
2. Verify zero-cross pulses on oscilloscope
3. Connect one channel with 40W incandescent bulb as load
4. Test on/off control from ESP32
5. Test dimming (for compatible loads)
6. Repeat for all channels

### Step 5: Integration Testing

- [ ] WiFi connectivity
- [ ] Cloud communication
- [ ] Physical switches working
- [ ] Voice control (Alexa/Google)
- [ ] Mobile app control

---

## 📐 PCB Layout Tips

### Isolation Requirements

- Maintain **8mm minimum** clearance between AC and DC traces
- Use **thick traces** for AC paths (minimum 2mm width)
- Add **isolation slots** in PCB for extra safety
- Place optocouplers at the **isolation barrier**

### Thermal Management

- Use **copper pour** under TRIACs for heatsinking
- Add **thermal vias** under power components
- Mount TRIACs on edge of PCB for external heatsink access
- Keep high-current traces short and wide

### Grounding

- Use **star ground** topology
- Separate analog and digital grounds
- Connect at single point near power supply

---

## 📦 Enclosure Design

### Requirements

- **Material**: Non-conductive (ABS plastic recommended)
- **Ventilation**: Slots for airflow (not large enough to touch components)
- **Mounting**: DIN rail or wall mount brackets
- **Access**: Removable cover with screws (not clips)
- **Cable Entry**: Strain relief glands
- **Labeling**: Clear warning labels for high voltage

### Dimensions

- Minimum internal space: 120mm × 80mm × 40mm
- Allow clearance for wire bending radius
- Consider future expansion

---

## 🔍 Troubleshooting

### Problem: Zero-cross not detected

- **Check**: Transformer connections and polarity
- **Check**: Bridge rectifier orientation
- **Check**: Optocoupler pins and resistor values
- **Test**: With oscilloscope at each stage

### Problem: TRIAC not switching

- **Check**: Gate resistor value (should be 100-180Ω)
- **Check**: Optocoupler orientation
- **Check**: ESP32 GPIO output voltage (should be 3.3V)
- **Test**: TRIAC with multimeter (should show near-zero resistance when triggered)

### Problem: Loads flickering

- **Check**: Zero-cross timing
- **Check**: TRIAC gate current
- **Add**: Snubber circuit across TRIAC
- **Check**: Load compatibility (some LEDs don't dim well)

### Problem: WiFi not connecting

- **Check**: 2.4GHz network availability
- **Check**: ESP32 power supply (needs >500mA peak)
- **Check**: Antenna connection
- **Reset**: WiFi credentials via physical switch

---

## 📸 Visual Reference

See **schematics/** folder for:
- Complete circuit diagram
- PCB layout
- 3D renders
- Assembly photos

---

## ✅ Final Checklist

Before permanent installation:

- [ ] All connections double-checked
- [ ] Proper fusing on AC input
- [ ] GFCI/RCD protection in place
- [ ] Enclosure properly sealed
- [ ] Warning labels affixed
- [ ] All tests passed
- [ ] Documentation completed
- [ ] Photos taken for reference

---

## 📞 Support

For connection issues:
- Review hardware README
- Check schematic diagrams
- Consult licensed electrician if unsure

---

**Safety Notice**: This guide is for educational purposes. Always follow local electrical codes and regulations. Have a licensed electrician verify your work before permanent installation.

---

**Version**: 1.0  
**Last Updated**: December 2024

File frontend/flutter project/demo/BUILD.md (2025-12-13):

# Quick Build Guide

## Build APK in 3 Steps

```bash
# 1. Install dependencies
flutter pub get

# 2. Build APK
flutter build apk --release

# 3. Find your APK
# Location: build/app/outputs/flutter-apk/app-release.apk
```

## Install on Phone

```bash
# Transfer APK to phone and tap to install
# OR use ADB:
adb install build/app/outputs/flutter-apk/app-release.apk
```

Done!

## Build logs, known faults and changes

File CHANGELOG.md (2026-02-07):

# Changelog

## v3.1 - Repository Reorganization (December 2024)

- Renamed `software_Team/` to `frontend/` and `hardware/PCB_Manufacturing/` to `hardware/pcb/`
- Removed redundant documentation files from root directory
- Updated all documentation references to reflect new folder structure

---

## v3.0 - Firmware Overhaul (December 2024)

### Architecture
- Multi-core FreeRTOS design: Core 1 for time-critical TRIAC control, Core 0 for network
- Thread-safe inter-core communication via FreeRTOS queues and mutexes
- Modular code organization (separate header/impl files)

### New Features
- Amazon Alexa voice control (via Espalexa, local network)
- Google Assistant support stubbed via SinricPro (not yet functional)
- Local REST API on port 8080 with full device/schedule/scene CRUD
- WebSocket server on port 81 for real-time state updates
- Scene and schedule automation with persistent storage
- Smooth fade transitions for dimmers and fans
- OTA firmware updates with rollback protection
- Enhanced cloud protocol for Google Apps Script

### Safety & Reliability
- Dual watchdog timers (Core 0: 15s, Core 1: 5s)
- Zero-cross signal monitoring with safety shutdown
- Auto-shutoff per device (configurable, default 1 hour)
- Heap monitoring and brownout protection

### Code Quality
- Comprehensive input validation on all API endpoints
- Structured logging with configurable levels (NONE through VERBOSE)
- Named constants for all magic numbers (see `config.h`)
- ISR-safe variable access with `volatile` and `portMUX_TYPE`

### Known Limitations
- SinricPro library not included by default — requires manual installation
- Requires ESP32 Arduino Core 2.0.x or later
- Minimum 4MB flash for OTA
- WiFi 2.4GHz only

### Breaking Changes from v2.1
- New local API on port 8080 (port 80 still redirects)
- Alexa devices now use custom names from configuration
- Uses new NVS preference keys (migration is automatic)

---

## v2.1 - Initial Release

- Basic 4-channel TRIAC control
- Amazon Alexa integration
- Google Apps Script cloud polling
- WiFi management with captive portal

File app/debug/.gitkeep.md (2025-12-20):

# Debug APK Directory

This directory contains debug builds of the Smart Home Controller Android app.

## Naming Convention

Debug APKs should follow this naming pattern:
```
smart-home-controller-v{major}.{minor}.{patch}-debug.apk
```

Examples:
- `smart-home-controller-v1.0.0-debug.apk`
- `smart-home-controller-v1.0.1-debug.apk`
- `smart-home-controller-v2.0.0-debug.apk`

## Building Debug APK

From the Flutter project directory:
```bash
cd "frontend/flutter project/demo"
flutter build apk --debug
cp build/app/outputs/flutter-apk/app-debug.apk ../../../app/debug/smart-home-controller-v1.0.0-debug.apk
```

## APK Characteristics

Debug APKs are:
- ✅ Include debug symbols
- ✅ Can be debugged with Android Studio
- ✅ Easier to test and diagnose issues
- ✅ Hot reload support in development
- ❌ Larger file size
- ❌ Not optimized for performance
- ❌ Should not be used in production

## Use Cases

Debug APKs are useful for:
- Development and testing
- Bug reproduction and debugging
- Internal QA testing
- Pre-release validation
- Logging and diagnostics

---

**Note:** APK files are not committed to the repository. This directory exists to provide a consistent location for placing built APKs.

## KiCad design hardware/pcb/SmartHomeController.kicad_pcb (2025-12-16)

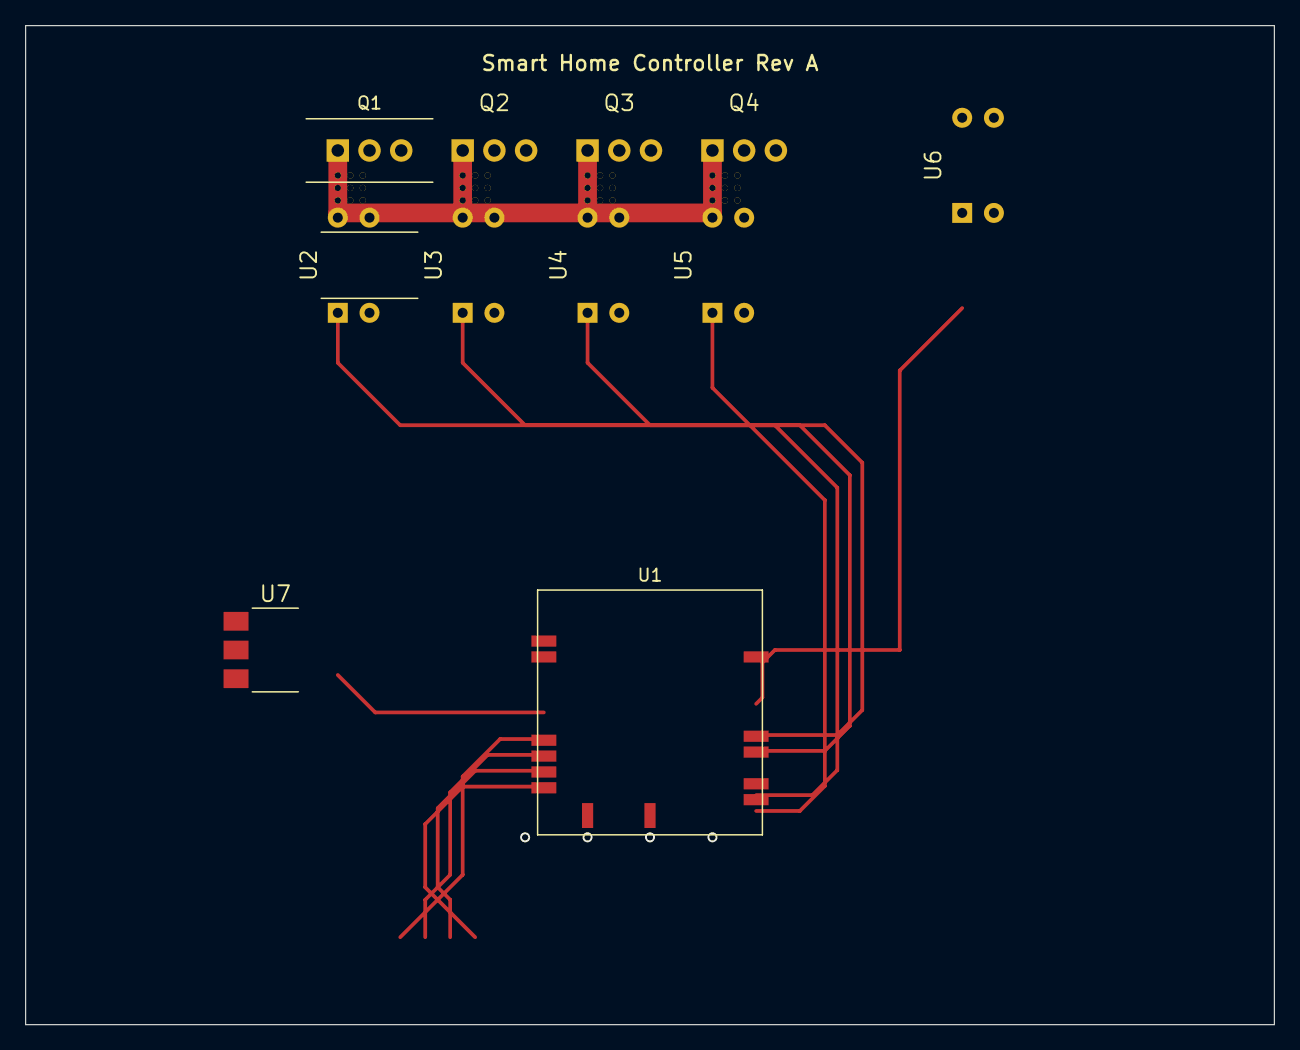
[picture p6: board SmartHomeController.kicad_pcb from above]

Board: 2 copper layers, 100.0 x 80.0 mm, 11 parts (0 on the bottom side), 11 nets.

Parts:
Q1, Q2, Q3, Q4: BT136-600E; TO-220-3_Vertical
U1: ESP32-WROOM-32
U2, U3, U4, U5: MOC3021; DIP-6_W7.62mm
U6: 4N25; DIP-6_W7.62mm
U7: AMS1117-5.0; SOT-223-3_TabPin2

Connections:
AC_L1: Q1.1, U2.6
AC_L2: Q2.1, U3.6
AC_L3: Q3.1, U4.6
AC_L4: Q4.1, U5.6
AC_LIVE: Q1.2, Q2.2, Q3.2, Q4.2, U7.3
GND: U1.1, U1.38, U1.39, U2.2, U3.2, U4.2, U5.2, U6.2, U6.4, U7.1
GPIO13: U1.15, U6.5
unnamed: Q1.3, U2.4
unnamed: Q2.3, U3.4
unnamed: Q3.3, U4.4
unnamed: Q4.3, U5.4

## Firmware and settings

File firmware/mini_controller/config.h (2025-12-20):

/**
 * Configuration file for Mini LED Controller
 * Edit these settings before uploading to your ESP32
 */

#ifndef MINI_CONFIG_H
#define MINI_CONFIG_H

// ================================================================
// DEVICE CONFIGURATION
// ================================================================
// Device name (shown in WiFi setup and dashboard)
#define DEVICE_NAME "Mini_LED_Controller"

// Firmware version
#define FIRMWARE_VERSION "1.0"

// ================================================================
// HARDWARE CONFIGURATION
// ================================================================
// Built-in LED pin
// Common values:
// - GPIO 2: Most ESP32 DevKit boards
// - GPIO 5: Some ESP32 boards
// - GPIO 16: NodeMCU-32S
// - GPIO 22: DOIT ESP32 DevKit
#define LED_PIN 2

// ================================================================
// PWM CONFIGURATION
// ================================================================
// PWM channel (0-15 available on ESP32)
#define PWM_CHANNEL 0

// PWM frequency in Hz (1-40000)
// 5000 Hz is good for LEDs
#define PWM_FREQUENCY 5000

// PWM resolution in bits (1-16)
// 8-bit = 256 levels (0-255)
// 10-bit = 1024 levels (0-1023)
#define PWM_RESOLUTION 8

// ================================================================
// NETWORK CONFIGURATION
// ================================================================
// Local API server port
#define LOCAL_SERVER_PORT 8080

// WebSocket server port
#define WEBSOCKET_PORT 81

// Cloud polling interval in milliseconds
// 5000 = 5 seconds
#define CLOUD_POLL_INTERVAL_MS 5000

// HTTP request timeout in milliseconds
#define HTTP_TIMEOUT_MS 10000

// Minimum URL length for validation
#define MIN_URL_LENGTH 10

// WiFi configuration portal timeout in seconds
// 180 = 3 minutes
#define WIFI_CONFIG_TIMEOUT 180

// ================================================================
// CLOUD INTEGRATION
// ================================================================
// Google Apps Script URL for cloud integration
// Leave empty ("") to disable cloud features
// Example: "https://script.google.com/macros/s/YOUR_SCRIPT_ID/exec"
// IMPORTANT: Replace with your own script URL before deployment
#define GOOGLE_SCRIPT_URL ""

// ================================================================
// MDNS CONFIGURATION
// ================================================================
// mDNS hostname (access device via http://hostname.local)
#define MDNS_HOSTNAME "mini-led"

// ================================================================
// DEFAULT LED STATE
// ================================================================
// Default LED state on power-up
#define DEFAULT_LED_STATE false  // false = OFF, true = ON

// Default brightness (0-100%)
#define DEFAULT_BRIGHTNESS 100

// Default LED name
#define DEFAULT_LED_NAME "Built-in LED"

// ================================================================
// DEBUG CONFIGURATION
// ================================================================
// Enable verbose serial output
// true = detailed logs, false = minimal logs
#define DEBUG_MODE false

// Serial baud rate
#define SERIAL_BAUD 115200

#endif // MINI_CONFIG_H

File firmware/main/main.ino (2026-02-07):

/**
 * 4-Channel Smart Home Controller Firmware v3.0
 * ==============================================================
 * ESP32-based TRIAC controller for AC load management.
 * 
 * Features:
 * - Multi-core FreeRTOS architecture (time-critical on Core 1, network on Core 0)
 * - Amazon Alexa voice control (via Espalexa)
 * - Google Apps Script cloud integration
 * - OTA updates with rollback protection
 * - Flutter app REST API + WebSocket
 * - Scene & schedule automation
 * - Safety features & watchdog monitoring
 * 
 * Note: Google Assistant (SinricPro) support is stubbed but not yet integrated.
 */

#include <WiFi.h>
#include <WebServer.h>
#include <HTTPClient.h>
#include <HTTPUpdate.h>
#include <WiFiClientSecure.h>
#include <ArduinoJson.h>
#include <Espalexa.h>
#include <Preferences.h>
#include <WiFiManager.h>
#include <ESPmDNS.h>
#include <esp_task_wdt.h>
#include <esp_ota_ops.h>
#include <time.h>
#include <WebSocketsServer.h>

// Project headers
#include "config.h"
#include "api.h"
#include "voice.h"

// ================================================================
// DATA STRUCTURES
// ================================================================
struct Device {
    String name;
    volatile DeviceType type;
    volatile bool state;
    volatile int brightness;  // Accessed from ISR, must be volatile
    volatile int fireTick;
    bool childLock;
    bool autoOffEnabled;
    PowerOnState powerOnBehavior;
    unsigned long lastOnTime;
    unsigned long totalRuntime;  // seconds
    int defaultBrightness;
};

struct Schedule {
    int16_t startMins;
    int16_t endMins;
    int8_t deviceId;
    int8_t startBrightness;
    int8_t endBrightness;
    bool active;
    uint8_t daysOfWeek;  // Bitmask: bit 0=Sun, 1=Mon, etc.
};

struct Scene {
    String name;
    bool active;
    struct SceneDevice {
        int8_t deviceId;
        bool state;
        int8_t brightness;
    } devices[4];
};

// ================================================================
// USER CONFIGURATION
// ================================================================
// Configure via Google Apps Script or web interface
String GOOGLE_SCRIPT_URL = "https://script.google.com/macros/s/AKfycbxJP31g9LhRulRHTbTd6KidEiBXlxCKfKcXkiUGe961IfNZDgHuoWAIif91PrPUQnHrIQ/exec";
String API_KEY = "smarthome-2024-[YourRandomStringikhdfg87y7fygdhgoesgysdygfdsy7fgdag7iufh9]";
String systemName = "Smart_Home_Hub";

// SinricPro credentials (loaded from cloud)
String sinricAppKey = "";
String sinricAppSecret = "";
String sinricDeviceIds[4] = {"", "", "", ""};

// ================================================================
// GLOBAL OBJECTS
// ================================================================
Espalexa alexaManager;
Preferences preferences;
WebServer redirectServer(80);
WebServer localServer(8080);
WebSocketsServer webSocket = WebSocketsServer(81);
hw_timer_t *timer = NULL;
portMUX_TYPE timerMux = portMUX_INITIALIZER_UNLOCKED;
QueueHandle_t deviceControlQueue;

// Queue message structure
struct DeviceControlMsg {
    int deviceId;
    bool state;
    int brightness;
    bool fade;
};

// ================================================================
// GLOBAL VARIABLES
// ================================================================
// Global device state
Device devices[4];
Schedule schedules[SCHEDULE_MAX_COUNT];
Scene scenes[SCENE_MAX_COUNT];
bool lastSwitchState[4];

// System state
volatile bool zeroCrossDetected = true;
volatile unsigned long lastZeroCrossTime = 0;
unsigned long bootTime = 0;
bool cloudConnected = false;
int currentError = ERR_NONE;

// Fade control
struct FadeState {
    bool active;
    int targetBrightness;
    int currentStep;
    int totalSteps;
    unsigned long lastStepTime;
    unsigned long stepInterval;
} fadeStates[4]; 

// ================================================================
// FORWARD DECLARATIONS
// ================================================================
void setDeviceState(int deviceId, bool state, int brightness, bool fade = false);
void saveDeviceConfig();
void saveSchedules();
void saveScenes();
void activateScene(int sceneId);
unsigned long getUptimeSeconds();
const char* getSignalStrength(int rssi);
void logMessage(LogLevel level, const char* format, ...);
void broadcastDeviceState(int deviceId); 

// ================================================================
// IMPLEMENTATION INCLUDES
// ================================================================
// Modular implementation files for professional code organization
// Included as .h for Arduino IDE compatibility
// These are included AFTER data structures and forward declarations are defined
#include "device_impl.h"
#include "storage_impl.h"
#include "isr_impl.h"
#include "automation_impl.h"
#include "api_impl.h"
#include "voice_impl.h"

// ================================================================
// UTILITY FUNCTIONS
// ================================================================

// Logging with levels
void logMessage(LogLevel level, const char* format, ...) {
    if (level > LOG_LEVEL) return;
    
    const char* levelStr[] = {"", "[ERROR]", "[WARN]", "[INFO]", "[DEBUG]", "[VERBOSE]"};
    Serial.print(levelStr[level]);
    Serial.print(" ");
    
    char buffer[256];
    va_list args;
    va_start(args, format);
    vsnprintf(buffer, sizeof(buffer), format, args);
    va_end(args);
    
    Serial.println(buffer);
}

// Calculate TRIAC fire tick from brightness percentage
int calculateFireTick(int percent) {
    if (percent >= 100) return 0;
    if (percent <= 0) return 100;
    return 100 - percent;
}

// Get uptime in seconds
unsigned long getUptimeSeconds() {
    return (millis() - bootTime) / 1000;
}

// Get WiFi signal strength description
const char* getSignalStrength(int rssi) {
    if (rssi >= RSSI_EXCELLENT) return "Excellent";
    if (rssi >= RSSI_GOOD) return "Good";
    if (rssi >= RSSI_FAIR) return "Fair";
    if (rssi >= RSSI_POOR) return "Poor";
    return "Weak";
}

// Convert time to minutes since midnight
int timeToMinutes(int hour, int minute) {
    return hour * 60 + minute;
}

// Get current time in minutes since midnight
int getCurrentMinutes() {
    struct tm timeinfo;
    if (!getLocalTime(&timeinfo)) return -1;
    return timeToMinutes(timeinfo.tm_hour, timeinfo.tm_min);
}
// ================================================================
// CORE 1: TIME-CRITICAL POWER CONTROL (PRO_CPU)
// ================================================================

// Hardware timer ISR for phase angle control
void IRAM_ATTR onTimerFire() {
    portENTER_CRITICAL_ISR(&timerMux);
    static int tickCounter = 0;
    tickCounter++;
    
    // Fire TRIACs at calculated phase angle
    for (int i = 0; i < 4; i++) {
        if (devices[i].state && devices[i].type != TYPE_SWITCH) {
            if (tickCounter >= devices[i].fireTick) {
                digitalWrite(TRIAC_PINS[i], HIGH);
            }
        }
    }
    
    if (tickCounter > PHASE_STEPS) tickCounter = 0;
    portEXIT_CRITICAL_ISR(&timerMux);
}

// Zero-cross detection ISR
void IRAM_ATTR onZeroCross() {
    portENTER_CRITICAL_ISR(&timerMux);
    
    // Update last zero-cross time for watchdog
    lastZeroCrossTime = millis();
    zeroCrossDetected = true;
    
    // Reset all TRIACs at zero crossing
    for (int i = 0; i < 4; i++) {
        if (devices[i].state) {
            if (devices[i].type == TYPE_SWITCH) {
                digitalWrite(TRIAC_PINS[i], HIGH);
            } else {
                digitalWrite(TRIAC_PINS[i], LOW);
            }
        } else {
            digitalWrite(TRIAC_PINS[i], LOW);
        }
    }
    
    portEXIT_CRITICAL_ISR(&timerMux);
}

// Check zero-cross signal health (call from Core 0 task)
void checkZeroCrossHealth() {
    if (millis() - lastZeroCrossTime > 100) {  // No signal for 100ms
        if (zeroCrossDetected) {
            logMessage(LOG_ERROR, "Zero-cross signal lost! Safety shutdown.");
            zeroCrossDetected = false;
            currentError = ERR_ZERO_CROSS_LOST;
            
            // Safety: Turn off all TRIACs - hardware first, then state
            // Order matters: Set pins LOW before clearing state to ensure
            // ISR doesn't re-trigger TRIACs during the transition
            for (int i = 0; i < 4; i++) {
                digitalWrite(TRIAC_PINS[i], LOW);
            }
            
            // Update state with critical section
            portENTER_CRITICAL(&timerMux);
            for (int i = 0; i < 4; i++) {
                devices[i].state = false;
            }
            portEXIT_CRITICAL(&timerMux);
        }
    }
}

// ================================================================
// PERSISTENCE & CONFIGURATION
// ================================================================

void saveDeviceConfig() {
    preferences.begin(PREF_NAMESPACE, false);
    preferences.putString(PREF_SYSTEM_NAME, systemName);
    
    for (int i = 0; i < 4; i++) {
        String prefix = PREF_DEVICE_PREFIX + String(i) + "_";
        preferences.putInt((prefix + "type").c_str(), (int)devices[i].type);
        preferences.putString((prefix + "name").c_str(), devices[i].name);
        preferences.putBool((prefix + "lock").c_str(), devices[i].childLock);
        preferences.putInt((prefix + "pon").c_str(), (int)devices[i].powerOnBehavior);
        preferences.putInt((prefix + "def_br").c_str(), devices[i].defaultBrightness);
        preferences.putBool((prefix + "auto").c_str(), devices[i].autoOffEnabled);
        
        // Save last state for POWER_ON_LAST behavior
        if (devices[i].powerOnBehavior == POWER_ON_LAST) {
            preferences.putBool((prefix + "last_st").c_str(), devices[i].state);
            preferences.putInt((prefix + "last_br").c_str(), devices[i].brightness);
        }
        
        // Save runtime statistics
        preferences.putULong((prefix + "runtime").c_str(), devices[i].totalRuntime);
    }
    
    preferences.end();
    logMessage(LOG_INFO, "Device configuration saved");
}

void loadDeviceConfig() {
    preferences.begin(PREF_NAMESPACE, true);
    systemName = preferences.getString(PREF_SYSTEM_NAME, "Smart_Home_Hub");
    
    for (int i = 0; i < 4; i++) {
        String prefix = PREF_DEVICE_PREFIX + String(i) + "_";
        devices[i].type = (DeviceType)preferences.getInt((prefix + "type").c_str(), TYPE_SWITCH);
        devices[i].name = preferences.getString((prefix + "name").c_str(), "Device " + String(i + 1));
        devices[i].childLock = preferences.getBool((prefix + "lock").c_str(), false);
        devices[i].powerOnBehavior = (PowerOnState)preferences.getInt((prefix + "pon").c_str(), POWER_ON_OFF);
        devices[i].defaultBrightness = preferences.getInt((prefix + "def_br").c_str(), 100);
        devices[i].autoOffEnabled = preferences.getBool((prefix + "auto").c_str(), true);
        devices[i].totalRuntime = preferences.getULong((prefix + "runtime").c_str(), 0);
        
        // Apply power-on behavior
        switch (devices[i].powerOnBehavior) {
            case POWER_ON_OFF:
                devices[i].state = false;
                devices[i].brightness = 100;
                break;
            case POWER_ON_ON:
                devices[i].state = true;
                devices[i].brightness = devices[i].defaultBrightness;
                break;
            case POWER_ON_LAST:
                devices[i].state = preferences.getBool((prefix + "last_st").c_str(), false);
                devices[i].brightness = preferences.getInt((prefix + "last_br").c_str(), 100);
                break;
            case POWER_ON_DEFAULT:
                devices[i].state = true;
                devices[i].brightness = devices[i].defaultBrightness;
                break;
        }
        
        devices[i].fireTick = calculateFireTick(devices[i].brightness);
        devices[i].lastOnTime = millis();
    }
    
    preferences.end();
    logMessage(LOG_INFO, "Device configuration loaded");
}

void saveSchedules() {
    preferences.begin(PREF_NAMESPACE, false);
    for (int i = 0; i < SCHEDULE_MAX_COUNT; i++) {
        String prefix = PREF_SCHEDULE_PREFIX + String(i) + "_";
        preferences.putShort((prefix + "start").c_str(), schedules[i].startMins);
        preferences.putShort((prefix + "end").c_str(), schedules[i].endMins);
        preferences.putChar((prefix + "dev").c_str(), schedules[i].deviceId);
        preferences.putChar((prefix + "sbr").c_str(), schedules[i].startBrightness);
        preferences.putChar((prefix + "ebr").c_str(), schedules[i].endBrightness);
        preferences.putBool((prefix + "act").c_str(), schedules[i].active);
        preferences.putUChar((prefix + "days").c_str(), schedules[i].daysOfWeek);
    }
    preferences.end();
    logMessage(LOG_INFO, "Schedules saved");
}

void loadSchedules() {
    preferences.begin(PREF_NAMESPACE, true);
    for (int i = 0; i < SCHEDULE_MAX_COUNT; i++) {
        String prefix = PREF_SCHEDULE_PREFIX + String(i) + "_";
        schedules[i].startMins = preferences.getShort((prefix + "start").c_str(), -1);
        schedules[i].endMins = preferences.getShort((prefix + "end").c_str(), -1);
        schedules[i].deviceId = preferences.getChar((prefix + "dev").c_str(), -1);
        schedules[i].startBrightness = preferences.getChar((prefix + "sbr").c_str(), 0);
        schedules[i].endBrightness = preferences.getChar((prefix + "ebr").c_str(), 100);
        schedules[i].active = preferences.getBool((prefix + "act").c_str(), false);
        schedules[i].daysOfWeek = preferences.getUChar((prefix + "days").c_str(), 0x7F);
    }
    preferences.end();
    logMessage(LOG_INFO, "Schedules loaded");
}

void saveScenes() {
    preferences.begin(PREF_NAMESPACE, false);
    for (int i = 0; i < SCENE_MAX_COUNT; i++) {
        String prefix = PREF_SCENE_PREFIX + String(i) + "_";
        preferences.putString((prefix + "name").c_str(), scenes[i].name);
        preferences.putBool((prefix + "act").c_str(), scenes[i].active);
        for (int j = 0; j < 4; j++) {
            String devPrefix = prefix + "d" + String(j) + "_";
            preferences.putChar((devPrefix + "id").c_str(), scenes[i].devices[j].deviceId);
            preferences.putBool((devPrefix + "st").c_str(), scenes[i].devices[j].state);
            preferences.putChar((devPrefix + "br").c_str(), scenes[i].devices[j].brightness);
        }
    }
    preferences.end();
    logMessage(LOG_INFO, "Scenes saved");
}

void loadScenes() {
    preferences.begin(PREF_NAMESPACE, true);
    for (int i = 0; i < SCENE_MAX_COUNT; i++) {
        String prefix = PREF_SCENE_PREFIX + String(i) + "_";
        scenes[i].name = preferences.getString((prefix + "name").c_str(), "");
        scenes[i].active = preferences.getBool((prefix + "act").c_str(), false);
        for (int j = 0; j < 4; j++) {
            String devPrefix = prefix + "d" + String(j) + "_";
            scenes[i].devices[j].deviceId = preferences.getChar((devPrefix + "id").c_str(), -1);
            scenes[i].devices[j].state = preferences.getBool((devPrefix + "st").c_str(), false);
            scenes[i].devices[j].brightness = preferences.getChar((devPrefix + "br").c_str(), 100);
        }
    }
    preferences.end();
    logMessage(LOG_INFO, "Scenes loaded");
}

// ================================================================
// 🎛️ DEVICE CONTROL
// ================================================================

void setDeviceState(int deviceId, bool state, int brightness, bool fade) {
    if (deviceId < 0 || deviceId >= 4) return;
    
    logMessage(LOG_DEBUG, "Setting device %d: state=%d, brightness=%d, fade=%d", 
               deviceId, state, brightness, fade);
    
    if (fade && devices[deviceId].type != TYPE_SWITCH) {
        // Start fade transition
        fadeStates[deviceId].active = true;
        fadeStates[deviceId].targetBrightness = state ? brightness : 0;
        fadeStates[deviceId].currentStep = 0;
        fadeStates[deviceId].totalSteps = FADE_STEPS;
        fadeStates[deviceId].lastStepTime = millis();
        fadeStates[deviceId].stepInterval = FADE_DURATION_MS / FADE_STEPS;
        devices[deviceId].state = true;  // Keep on during fade
    } else {
        // Immediate change - use critical section to protect ISR-accessed variables
        portENTER_CRITICAL(&timerMux);
        devices[deviceId].state = state;
        devices[deviceId].brightness = state ? brightness : 0;
        devices[deviceId].fireTick = calculateFireTick(devices[deviceId].brightness);
        portEXIT_CRITICAL(&timerMux);
        
        if (state) {
            devices[deviceId].lastOnTime = millis();
        }
    }
    
    // Broadcast to WebSocket clients
    broadcastDeviceState(deviceId);
}

void processFadeTransitions() {
    for (int i = 0; i < 4; i++) {
        if (!fadeStates[i].active) continue;
        
        unsigned long now = millis();
        if (now - fadeStates[i].lastStepTime >= fadeStates[i].stepInterval) {
            fadeStates[i].currentStep++;
            fadeStates[i].lastStepTime = now;
            
            // Use critical section to protect ISR-accessed variables
            portENTER_CRITICAL(&timerMux);
            if (fadeStates[i].currentStep >= fadeStates[i].totalSteps) {
                // Fade complete
                devices[i].brightness = fadeStates[i].targetBrightness;
                devices[i].state = (devices[i].brightness > 0);
            } else {
                // Calculate intermediate brightness
                int startBrightness = devices[i].brightness;
                int range = fadeStates[i].targetBrightness - startBrightness;
                float progress = (float)fadeStates[i].currentStep / fadeStates[i].totalSteps;
                devices[i].brightness = startBrightness + (int)(range * progress);
            }
            
            devices[i].fireTick = calculateFireTick(devices[i].brightness);
            portEXIT_CRITICAL(&timerMux);
            
            // Update fade state after critical section (not accessed by ISR)
            if (fadeStates[i].currentStep >= fadeStates[i].totalSteps) {
                fadeStates[i].active = false;
            }
        }
    }
}

void activateScene(int sceneId) {
    if (sceneId < 0 || sceneId >= SCENE_MAX_COUNT) return;
    if (!scenes[sceneId].active) return;
    
    logMessage(LOG_INFO, "Activating scene: %s", scenes[sceneId].name.c_str());
    
    for (int i = 0; i < 4; i++) {
        if (scenes[sceneId].devices[i].deviceId >= 0) {
            int devId = scenes[sceneId].devices[i].deviceId;
            setDeviceState(devId, 
                          scenes[sceneId].devices[i].state,
                          scenes[sceneId].devices[i].brightness,
                          true);  // Use fade transition
        }
    }
}

void processSchedules() {
    int currentMins = getCurrentMinutes();
    if (currentMins < 0) return;  // Time not available
    
    struct tm timeinfo;
    if (!getLocalTime(&timeinfo)) return;
    int currentDay = timeinfo.tm_wday;  // 0=Sunday
    
    for (int i = 0; i < SCHEDULE_MAX_COUNT; i++) {
        if (!schedules[i].active) continue;
        if (schedules[i].deviceId < 0 || schedules[i].deviceId >= 4) continue;
        
        // Check if schedule is active for current day
        if (!(schedules[i].daysOfWeek & (1 << currentDay))) continue;
        
        // Check if current time matches schedule
        if (currentMins >= schedules[i].startMins && currentMins < schedules[i].endMins) {
            // Calculate brightness based on time progression
            int duration = schedules[i].endMins - schedules[i].startMins;
            int elapsed = currentMins - schedules[i].startMins;
            float progress = (float)elapsed / duration;
            
            int targetBrightness = schedules[i].startBrightness + 
                (int)((schedules[i].endBrightness - schedules[i].startBrightness) * progress);
            
            bool targetState = (targetBrightness > 0);
            
            // Only update if different from current state
            if (devices[schedules[i].deviceId].state != targetState ||
                devices[schedules[i].deviceId].brightness != targetBrightness) {
                setDeviceState(schedules[i].deviceId, targetState, targetBrightness, true);
            }
        }
    }
}

void updateRuntimeStatistics() {
    static unsigned long lastUpdate = 0;
    unsigned long now = millis();
    
    if (now - lastUpdate >= 1000) {  // Update every second
        for (int i = 0; i < 4; i++) {
            if (devices[i].state) {
                devices[i].totalRuntime++;
            }
        }
        lastUpdate = now;
    }
}

void checkAutoOff() {
    if (AUTO_OFF_MS == 0) return;
    
    unsigned long now = millis();
    for (int i = 0; i < 4; i++) {
        if (devices[i].state && devices[i].autoOffEnabled) {
            if (now - devices[i].lastOnTime > AUTO_OFF_MS) {
                logMessage(LOG_INFO, "Auto-off triggered for device %d", i);
                setDeviceState(i, false, 0, true);
            }
        }
    }
}

// ================================================================
// OTA UPDATE SYSTEM
// ================================================================
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
void loop() {
    // Core 1 handles only time-critical voice assistant polling
    // All other logic is in Core 0 task
    alexaManager.loop();
    
    // Minimal delay to prevent watchdog triggers
    delay(1);
}

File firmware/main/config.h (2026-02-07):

/**
 * Configuration Constants for Smart Home Controller
 * Version: 3.0
 */

#ifndef CONFIG_H
#define CONFIG_H

// ================================================================
// FIRMWARE VERSION
// ================================================================
#define FIRMWARE_VERSION 3.0
#define FIRMWARE_BUILD "PROD-001"

// ================================================================
// HARDWARE CONFIGURATION
// ================================================================
// Zero-Cross Detection Pin
#define ZCD_PIN 13

// TRIAC Control Pins (4 channels)
const int TRIAC_PINS[4] = {16, 17, 18, 19};

// Physical Switch Pins (4 channels)
const int SWITCH_PINS[4] = {32, 33, 25, 26};

// Optional Temperature Sensor (set to -1 if not available)
#define TEMP_SENSOR_PIN -1

// LED indicator pin (for OTA updates)
#ifndef LED_BUILTIN
#define LED_BUILTIN 2  // ESP32 built-in LED on GPIO 2
#endif

// ================================================================
// TIMING CONFIGURATION
// ================================================================
// Phase angle control timing (microseconds)
#define TIMER_INTERVAL_US 100
#define PHASE_STEPS 100

// Debounce delay for physical switches (milliseconds)
#define SWITCH_DEBOUNCE_MS 50

// Safety auto-off timer (milliseconds, 0 = disabled)
#define AUTO_OFF_MS 3600000  // 1 hour

// Factory reset long-press duration (milliseconds)
#define FACTORY_RESET_DURATION_MS 10000  // 10 seconds

// ================================================================
// NETWORK CONFIGURATION
// ================================================================
// Cloud polling interval (milliseconds)
#define CLOUD_POLL_INTERVAL_MS 2500  // 2.5 seconds

// WiFi reconnection settings
#define WIFI_RECONNECT_INTERVAL_MS 5000
#define WIFI_RECONNECT_MAX_ATTEMPTS 5
#define WIFI_RECONNECT_BACKOFF_MULTIPLIER 2

// HTTP request timeout (milliseconds)
#define HTTP_TIMEOUT_MS 15000

// WebSocket ping interval (milliseconds)
#define WEBSOCKET_PING_INTERVAL_MS 30000

// ================================================================
// OTA UPDATE CONFIGURATION
// ================================================================
#define OTA_CHECK_INTERVAL_MS 3600000  // Check every hour
#define OTA_PARTITION_LABEL "app0"

// ================================================================
// WATCHDOG CONFIGURATION
// ================================================================
#define WDT_TIMEOUT_CORE0 15  // seconds
#define WDT_TIMEOUT_CORE1 5   // seconds (time-critical)

// ================================================================
// NTP CONFIGURATION
// ================================================================
const char* NTP_SERVER = "pool.ntp.org";
const long GMT_OFFSET_SEC = 19800;  // IST: UTC+5:30
const int DAYLIGHT_OFFSET_SEC = 0;

// ================================================================
// LOGGING CONFIGURATION
// ================================================================
enum LogLevel {
    LOG_NONE = 0,
    LOG_ERROR = 1,
    LOG_WARN = 2,
    LOG_INFO = 3,
    LOG_DEBUG = 4,
    LOG_VERBOSE = 5
};

#define LOG_LEVEL LOG_INFO  // Change to LOG_DEBUG for development

// ================================================================
// MEMORY CONFIGURATION
// ================================================================
#define JSON_BUFFER_SIZE 2048
#define SCHEDULE_MAX_COUNT 10
#define SCENE_MAX_COUNT 10

// ================================================================
// DEVICE TYPES
// ================================================================
enum DeviceType {
    TYPE_SWITCH = 0,
    TYPE_FAN = 1,
    TYPE_DIMMER = 2
};

// ================================================================
// DEVICE STATES
// ================================================================
enum PowerOnState {
    POWER_ON_OFF = 0,      // Always off
    POWER_ON_ON = 1,       // Always on
    POWER_ON_LAST = 2,     // Remember last state
    POWER_ON_DEFAULT = 3   // Use default brightness
};

// ================================================================
// TRANSITION SETTINGS
// ================================================================
#define FADE_DURATION_MS 1000  // Default fade duration
#define FADE_STEPS 20          // Number of steps in fade transition

// ================================================================
// PREFERENCES KEYS
// ================================================================
#define PREF_NAMESPACE "smarthome"
#define PREF_SYSTEM_NAME "sys_name"
#define PREF_DEVICE_PREFIX "dev_"
#define PREF_SCHEDULE_PREFIX "sched_"
#define PREF_SCENE_PREFIX "scene_"
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

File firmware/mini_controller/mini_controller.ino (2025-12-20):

/**
 * ⚡ Mini Controller: ESP32 Built-in LED Remote Control v1.0
 * ==========================================================
 * Simple firmware for controlling ESP32's built-in LED remotely
 * 
 * Features:
 * - WiFi connectivity with captive portal
 * - REST API for LED control (on/off/brightness)
 * - WebSocket real-time updates
 * - Google Apps Script cloud integration
 * - Web dashboard compatible
 * - PWM brightness control (0-100%)
 * 
 * Hardware:
 * - ESP32 DevKit or compatible
 * - Built-in LED (typically GPIO 2)
 * 
 * Copyright (c) 2024 - Smart Home Controller Project
 */

#include <WiFi.h>
#include <WebServer.h>
#include <HTTPClient.h>
#include <ArduinoJson.h>
#include <WiFiManager.h>
#include <ESPmDNS.h>
#include <WebSocketsServer.h>

// Project configuration
#include "config.h"

// Google Apps Script URL (from config or override here)
String googleScriptURL = GOOGLE_SCRIPT_URL;
String API_KEY = "smarthome-2024-[YourRandomStringikhdfg87y7fygdhgoesgysdygfdsy7fgdag7iufh9]";

// ================================================================
// GLOBAL OBJECTS
// ================================================================
WebServer server(LOCAL_SERVER_PORT);
WebServer redirectServer(80);
WebSocketsServer webSocket = WebSocketsServer(WEBSOCKET_PORT);
HTTPClient http;

// ================================================================
// DEVICE STATE
// ================================================================
struct LEDState {
    bool state;           // On/Off
    int brightness;       // 0-100%
    String name;          // Device name
    unsigned long lastOnTime;
    unsigned long totalRuntime;  // seconds
} led;

// System state
unsigned long bootTime = 0;
bool cloudConnected = false;
String systemUID;

// ================================================================
// UTILITY FUNCTIONS
// ================================================================

void logMessage(const char* level, const char* message) {
    Serial.print("[");
    Serial.print(level);
    Serial.print("] ");
    Serial.println(message);
}

unsigned long getUptimeSeconds() {
    return (millis() - bootTime) / 1000;
}

// Convert brightness percentage (0-100) to PWM value (0-255)
int brightnessToLEDC(int percent) {
    if (percent <= 0) return 0;
    if (percent >= 100) return 255;
    return map(percent, 0, 100, 0, 255);
}

// ================================================================
// LED CONTROL
// ================================================================
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

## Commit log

2025-12-13 Add null check for event parameter in switchTab function
2025-12-13 Fix compilation errors by reordering includes and declarations
    [main.ino]
2025-12-16 Create complete KiCad 6.0 project files with manufacturing specifications
    [BOM.csv, SmartHomeController.kicad_pcb, SmartHomeController.kicad_sch]
2025-12-16 Fix code review issues: MOC3021 pin overlap and TRIAC gate net assignments
    [SmartHomeController.kicad_pcb, SmartHomeController.kicad_sch]
2025-12-16 Improve design: Increase MOC3021 pin spacing, enforce strict isolation keepout, add JLCPCB stackup specs
    [SmartHomeController.kicad_pcb, SmartHomeController.kicad_sch]
2025-12-19 Reorganize repository structure and remove redundant documentation
    - Rename software_Team to frontend for professional naming
    - Rename hardware/PCB_Manufacturing to hardware/pcb
    - Remove redundant documentation files (FINAL_SUMMARY.md, IMPLEMENTATION_SUMMARY.md, etc.)
    - Update all cross-references in documentation to new paths
    - Clean root directory from 16 to 9 essential markdown files
    [BOM.csv, SmartHomeController.kicad_pcb, SmartHomeController.kicad_sch]
2025-12-20 Add mini controller firmware for ESP32 built-in LED control
2025-12-20 Add simple LED test example for mini controller
2025-12-20 Fix LED_BUILTIN and ArduinoJson v7 API compilation errors
    [config.h, main.ino]
2025-12-20 Add volatile keyword and critical sections for thread-safe ISR access
2025-12-20 Fix syntax error - remove extra closing brace in processFadeTransitions
    [main.ino]
2025-12-20 Fix race condition in physical switch handler - add critical section for state read
    [main.ino]
2025-12-20 Fix race condition - read state and brightness atomically in switch handler
    [main.ino]
2025-12-20 Add modular architecture - create separate modules for device, storage, ISR, and automation
2025-12-21 Add back buttons and update all pages for production
2025-12-21 Fix light_page.dart bracket structure and indentation
